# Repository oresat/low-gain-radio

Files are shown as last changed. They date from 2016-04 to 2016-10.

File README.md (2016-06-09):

# OreSat "Low Gain Radio" board

<p align="center">
  
</p>

## Overview

The Low Gain Radio module is part of the sputnik capstone project and is the communications pipeline for the CubeSat.  

OreSat to LGR block diagram  

The module is centered around a microcontroller with an integrated transceiver and RF front end. Commands will be sent and received through this module. In most cases the system controller will assist in executing those commands. Communication with the system controller is done via a UART connection between the two modules.

## Main Topics
[Parts Selection](https://github.com/oresat/low-gain-radio/blob/master/docs/Parts_Selection.md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)  
[Bill of Materials](https://github.com/oresat/low-gain-radio/blob/master/docs/low-gain-radio_BOM.xlsx)  
[Eagle Schematic](https://github.com/oresat/low-gain-radio/blob/master/eagle/low-gain-radio.sch)    
[Eagle Layout](https://github.com/oresat/low-gain-radio/blob/master/eagle/low-gain-radio.brd)    
[Test Plan](https://github.com/oresat/low-gain-radio/blob/master/docs/Test_Plan_Sputnik_Capstone.md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)    

## Contents

datasheets - datasheets for components used

docs - documentation

eagle - contains Schematic and PCB layout for the Low Gain Radio

tools - contains firmware and tools for compiling/debugging

## Project team

Industry Sponsor: Andrew Greenberg (adg@ece.pdx.edu)

Faculty Advisor: Dr. Christof Teuscher (teuscher@pdx.edu)

* Capstone Team
* 
    * Jake Heath (jakeheath@gmail.com)

    * Shan Quinney (quinney@pdx.edu) 

    * William Harrington (wrh2@pdx.edu)

    * Mike Mathis (mdmathis@gmail.com)

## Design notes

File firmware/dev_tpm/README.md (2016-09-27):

# dev_tpm

* This directory is for development of the tpm driver

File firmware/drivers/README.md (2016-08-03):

### Drivers for peripherals on microcontroller

* transceiver

* v1_2
	* V1_2 refers to the board revision. Specific configuration for this version of the board

* clocks

* led

* port

* uart

* spi

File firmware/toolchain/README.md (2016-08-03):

### Code Style

* see psas.astylerc

### Openocd configuration

#### Programmer

* In the olimex programmer cfg file for openocd you may need to change this line if you are using a different programmer

* select appropriate programmer by hand

* This one:
* source [find interface/ftdi/olimex-arm-usb-tiny-h.cfg]
* OR:
source [find interface/ftdi/olimex-arm-usb-ocd.cfg]

#### Configuration files

* olimex_swd_kinetis.cfg
* gdboocd_ocd.cmd

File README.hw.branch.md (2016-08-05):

## Branch for kw0x breakout board

### Branch rulez

#### Each version of hardware will have it's own branch

* Don't merge this branch into another hw branch 
* Don't merge this branch back into 'master'
* New hardware derived from this hardware should have it's own branch

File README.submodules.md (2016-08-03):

* Check the .gitmodules file for updates

* CMSIS from the ARM-software Github account
  * https://github.com/ARM-software/CMSIS.git

* common submodule commands
 * git submodule init
 * git submodule update

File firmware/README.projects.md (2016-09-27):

### Current project types for lgr 

* dev\_\*
 * Development code and experiments

* test
 * Accumulated tests that should execute before committing to main branch

* flight
 * This project is analogous to the 'release'. This is what is programmed to the flight board instance.

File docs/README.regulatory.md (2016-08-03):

# 70 cm Low Gain Radio Communications Transceiver

## Regulatory :us:

* **Frequency:** 436.5MHz  (70cm (420-450 MHz)) 
* **Power:** 1W
* **Band Plan** (Ref: http://www.arrl.org/band-plan)
    * 435.00-438.00	Satellite only (internationally)	

### Power Regulations

* There is a geographical power limitation on the 70cm band which does not apply at this frequency or output power.

   * Ref: FCC §97.313 Transmitter power standards. 

> (f) No station may transmit with a transmitter power exceeding 50 W PEP on the
>     UHF 70 cm band from an area specified in paragraph (a) of footnote US270 in
>     §2.106, unless expressly authorized by the FCC after mutual agreement, on a
>     case-by-case basis, between the District Director of the applicable field
>     facility and the military area frequency coordinator at the applicable military
>     base. An Earth station or telecommand station, however, may transmit on the
>     435-438 MHz segment with a maximum of 611 W effective radiated power (1 kW
>     equivalent isotropically radiated power) without the authorization otherwise
>     required. The transmitting antenna elevation angle between the lower half-power
>     (−3 dB relative to the peak or antenna bore sight) point and the horizon must
>     always be greater than 10°. 

### Auxiliary Station Operation

**NOTE** *This needs review*

* **Ref:**  http://www.arrl.org/auxiliary-station-faq

> What is an auxiliary station?- When an amateur station, such as a repeater, is
> remotely controlled over a radio link, there is another station involved--the
> station doing the controlling. This "control" station is, under the FCC rules,
> called an auxiliary station defined by the FCC as "An amateur station, other
> than a message forwarding system, that is transmitting comunications
> point-to-point within a system of cooperating amateur stations [97.3(a)(7)]."
> There are a few important rules that apply to auxiliary stations: 1) All
> amateurs, except Novices, may put auxiliary stations on the air [97.201(a)]. 2)
> An auxiliary station may transmit only on the 2 m and shorter wavelength bands,
> except the 144.0-144.5 MHz, 145.8-146.0 MHz, 219-220 MHz, 222.00-222.15 MHz,
> 431-433 MHz, and 435-438 MHz segments. 3) When there is interference, licensees
> are equally responsible for solving the interference, except where one station
> is coordinated and the other is not [97.201(c)]. Control links should be
> coordinated. 4) An auxiliary station may, under certain circumstances, be
> automatically controlled and may send one-way transmissions [97.201(d), (e)].

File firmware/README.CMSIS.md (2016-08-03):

### CMSIS
  * Submodule in lgr

#### Cortex Microcontroller Software Interface Standard

* http://www.arm.com/products/processors/cortex-m/cortex-microcontroller-software-interface-standard.php

#### lgr CMSIS usage

* Check included headers for CMSIS support. For example:
 * #include "core_cm0plus.h"
 * #include "cmsis_gcc.h"

```
	CMSIS
	├── ARM.CMSIS.pdsc
	├── CMSIS
	│   ├── CMSIS_END_USER_LICENCE_AGREEMENT.pdf
	│   ├── CMSIS_END_USER_LICENCE_AGREEMENT.rtf
	│   ├── DAP
	│   ├── Documentation
	│   ├── Driver
	│   ├── DSP_Lib
	│   ├── Include
	│   │   ├── arm_common_tables.h
	│   │   ├── arm_const_structs.h
	│   │   ├── arm_math.h
	│   │   ├── cmsis_armcc.h
	│   │   ├── cmsis_armcc_V6.h
	│   │   ├── cmsis_gcc.h
	│   │   ├── core_cm0.h
	│   │   ├── core_cm0plus.h
	│   │   ├── core_cm3.h
	│   │   ├── core_cm4.h
	│   │   ├── core_cm7.h
	│   │   ├── core_cmFunc.h
	│   │   ├── core_cmInstr.h
	│   │   ├── core_cmSimd.h
	│   │   ├── core_sc000.h
	│   │   └── core_sc300.h
	│   ├── index.html
	│   ├── Lib
	│   ├── Pack
	│   ├── RTOS
	│   ├── SVD
	│   └── Utilities
	├── Device
	│   ├── ARM
	│   ├── _Template_Flash
	│   └── _Template_Vendor
	└── README.md
```

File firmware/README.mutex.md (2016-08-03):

#### FYI: Atomic instructions

* http://infocenter.arm.com/help/index.jsp?topic=/com.arm.doc.dai0321a/BIHEJCHB.html
 * The Cortex-M0 and Cortex-M0+ processors do not have exclusive access instructions.

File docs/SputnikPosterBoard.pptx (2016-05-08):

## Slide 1

Sputnik: Command, Control and Communications Board for Cubesat

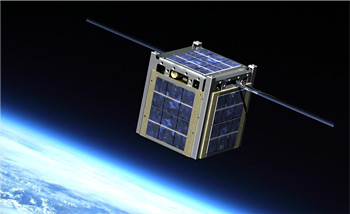
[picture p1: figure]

Description
The Portland State Aerospace Society (PSAS) needs a command, control, and communications system for their CubeSat project. The focus of this project will be rapidly prototyping this module. The code name for the module is Sputnik because of it's requirements to be a simple, reliable space system.
Sputnik will have the following responsibilities:
Long distance RF communications to and from a 400km Low Earth Orbit
Controlling and communicating with a payload that is housed within the CubeSat
On top of fulfilling these duties, it will need to be able to deal with a temperature range of -40C to 50C and radiation events that could cause components to latch up. It will have to have a way for dealing with these events such as rebooting the entire module and/or fault-tolerance.
Aspects of this project include
Building a C3 system from scratch to meet
The harsh environment of space
Compliance with governmental regulations
Programming the system to perform the aforementioned duties
Testing and verifying the device
Documentation
Adhering to the PSAS open-source standard

Concept
The Sputnik module is split up in two separate submodules: the radio transceiver module and control module. It is connected to two other important modules within the CubeSat: the payload module and power module.
At the heart of Sputnik is the Radio transceiver which contains the KW0x and a radio infrastructure. This is the communications pipeline. It is connected to the Control Module via UART.
The radio infrastructure in this submodule will consist of a bandpass filter, AC blocking network, aLow-Noise Amplifier, and a Power Amplifier. It will be expecting a 50ohm impedance for its load (the antenna) which is not within the scope of this project. It will need to be capable of producing 1 Watt of power for long distance communication.
The Payload is its own separate module that is not within the scope of this project. What it contains is undetermined but it can be assumed that it will consist of other electronic modules capable of UART communication.
The Control Module is composed entirely of rad-hard parts. It is the lifeline of Sputnik. It will be responsible for detecting the first sign of trouble and rebooting the module. It is also connected to the Power module via I2C and to the Payload via UART. Provisions will need to be made to ensure that the microcontroller is given a little bit of charge during a reboot cycle so that it can maintain control.
The entire architecture will have to run off of a single cell Li-Po battery pack that is connected to the Power module. The Power Management System will take input power from 6 photovoltaic cells. It will use this input power to charge the battery and power the module when possible. When there is no input power, the module will run off the battery.

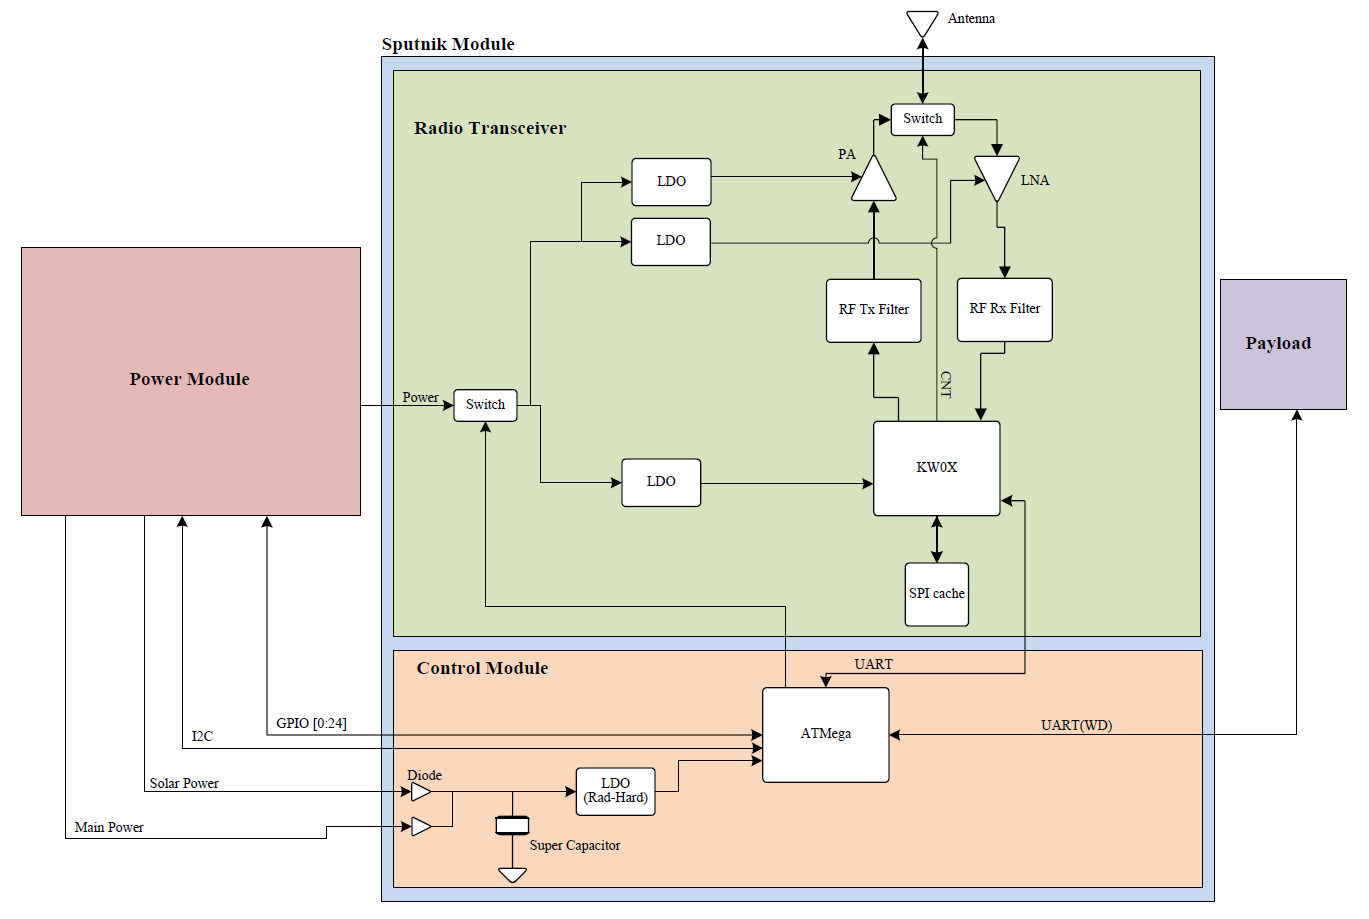
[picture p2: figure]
Phase 1 Low Level Diagram
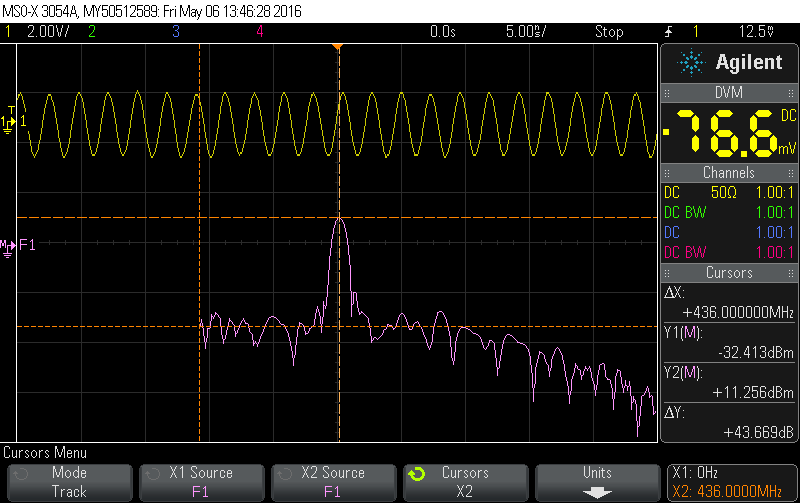
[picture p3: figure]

Department of Electrical and Computer Engineering

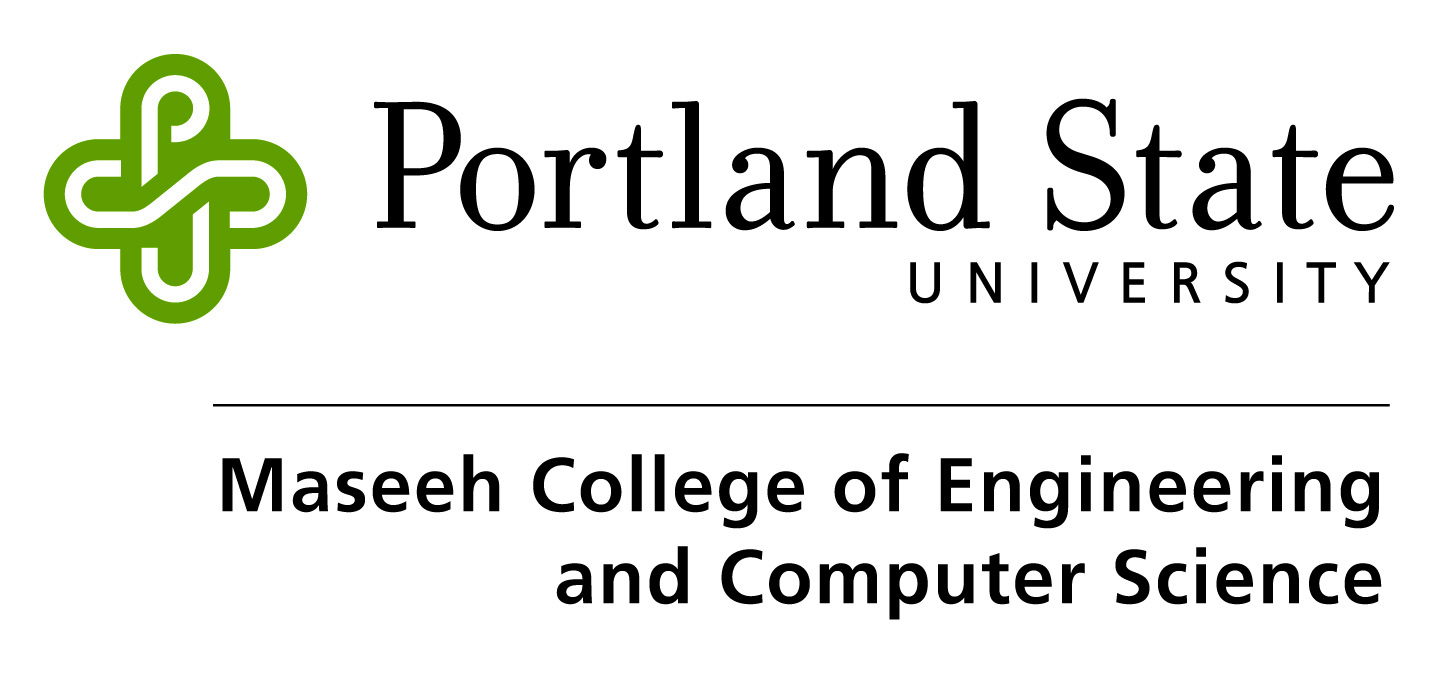
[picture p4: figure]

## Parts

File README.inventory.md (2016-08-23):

### Version 1.2 boards

* Three boards total from OSHPARK.

* DIO0 Modwire: DIO0 was incorrectly connected to RESET (RF) during design.
 * This prevents DIO0 from being used as a Packet Mode information pin.
 * Reference: Table 7-3 p.7-7 MKW01xxRM Reference Manual, Rev. 3, 04/2016

#### Board A

* DIO0 Modwire	PTE30 -> RESET (RF)    Wed 02 August 2016
* Location: Jake Heath

#### Board B

* DIO0 Modwire
* Fails to program flash. Thu 18 August 2016 13:12:48 (PDT)
* Location: K Wilson 

#### Board C

* DIO0 Modwire
* Program flash but fails at switch to PLL clock. Thu 18 August 2016 13:13:02 (PDT)
* Location: K Wilson

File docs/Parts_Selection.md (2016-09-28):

# Parts Selection for Low Gain Radio  
**Table of Contents**
 * [Microcontroller](https://github.com/oresat/low-gain-radio/blob/v1_2/docs/Parts_Selection.md#u1-nxp-mkw01z128)   
 * [PA](https://github.com/oresat/low-gain-radio/blob/v1_2/docs/Parts_Selection.md#u2-skyworks-sky65116)  
 * [LNA](https://github.com/oresat/low-gain-radio/blob/v1_2/docs/Parts_Selection.md#u8-maacom-maal-010704)  
 * [RF-Switch](https://github.com/oresat/low-gain-radio/blob/v1_2/docs/Parts_Selection.md#u9-rfmd-rf3025tr7)  
 * [MCU LDO](https://github.com/oresat/low-gain-radio/blob/v1_2/docs/Parts_Selection.md#u4-texas-instruments-lp5907mfx-33)  
 * [PA LDO](https://github.com/oresat/low-gain-radio/blob/v1_2/docs/Parts_Selection.md#u7-st-microelectronics-dm00102135)
 * [LNA LDO](https://github.com/oresat/low-gain-radio/blob/v1_2/docs/Parts_Selection.md#u6-texas-instruments-lp5907mfx-33)  
 * [SPI Cache](https://github.com/oresat/low-gain-radio/blob/v1_2/docs/Parts_Selection.md#u3-winbond-w25q80dvsnig-tr)  
 * [Crystal](https://github.com/oresat/low-gain-radio/blob/v1_2/docs/Parts_Selection.md#y1-epson-fa-20h)  
 * [JTAG Connector](https://github.com/oresat/low-gain-radio/blob/v1_2/docs/Parts_Selection.md#cm1-cnc-tech-3220-10-0100-00)
 * [40 Pin Header](https://github.com/oresat/low-gain-radio/blob/v1_2/docs/Parts_Selection.md#y1-harwin-inc-m50-3202045)
 * [MCX Connector](https://github.com/oresat/low-gain-radio/blob/v1_2/docs/Parts_Selection.md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) 
 * [Inverter](https://github.com/oresat/low-gain-radio/blob/v1_2/docs/Parts_Selection.md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)
 * [RF Shield (1)](https://github.com/oresat/low-gain-radio/blob/v1_2/docs/Parts_Selection.md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)
 * [RF Shield (2)](https://github.com/oresat/low-gain-radio/blob/v1_2/docs/Parts_Selection.md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)
 * [Electrolytic Capacitor](https://github.com/oresat/low-gain-radio/blob/v1_2/docs/Parts_Selection.md#c43-avx-tajc107k010rnj)
 * [LEDs](https://github.com/oresat/low-gain-radio/blob/v1_2/docs/Parts_Selection.md#leds)
 * [Capacitors](https://github.com/oresat/low-gain-radio/blob/v1_2/docs/Parts_Selection.md#capacitors)
 * [Inductors](https://github.com/oresat/low-gain-radio/blob/v1_2/docs/Parts_Selection.md#inductors)
 * [Resistors](https://github.com/oresat/low-gain-radio/blob/v1_2/docs/Parts_Selection.md#resistors)

#### Format note  
Eagle Referance, Manufacturer, Manufacturer's Part Number  
Vendor  
Vendor Part No  
Datasheet  
Reasons  
Rad-hard Analogue  

#### U1 NXP MKW01Z128:  
Part: Microcontroller  
Vendor: Digi-Key  
Vendor Part No.: MKW01Z128CHN-ND  
[Datasheet](http://cache.nxp.com/files/microcontrollers/doc/data_sheet/MKW01Z128.pdf)  
Reasons: Requirement for the project. Chosen since it has an integrated transceiver, needed peripherals and meets JDEC standards.     
Rad-Hard Analogue: N/A  
  
#### U2 SkyWorks SKY65116: 
Part: Power Amplifier  
Vendor: Mouser    
Vendor Part No.: 873-SKY65116-21  
[Datasheet](http://www.skyworksinc.com/uploads/documents/SKY65116_200510I.pdf)  
Reasons: Able to provide 1W power output. Also has low voltage rails, but asks for a higher current draw (~1-1.3A).  
Rad-Hard Analogue: N/A  
  
#### U8 MAACOM MAAL-010704:  
Part: Low Noise Amplifier  
Vendor: Digi-Key    
Vendor Part No.: 1465-1261-1-ND  
[Datasheet](http://cdn.macom.com/datasheets/MAAL-010704.pdf)  
Reasons: Provides >0.7dB Noise level at average space temperatures (~-40C) at 436.5MHz. At different temperatures, we see an increase of about .1~.2dBs at the same frequency, so it's not perfect though. 
Rad-Hard Analogue: N/A  
**_Alternatives_**     
Part No.: HMC616LP3    
Manufacturer: Hittite  
[Datasheet](http://www.radiant.su/other/hittite/pdf/hmc616lp3.pdf)  
Reasons: This part would be better than the one selected. Provides >0.6dB Noise at all temperatures and at most frequencies. At average space temperatures, around 0.3dB Noise level at 436.5MHz. However it is vaporware in the USA. It might be available from China, however shipping and part price is expensive/long.  
Part No.: SKY67110_396LF  
Manufacturer: SkyWorks  
[Datasheet](http://www.skyworksinc.com/uploads/documents/SKY67110_396LF_201792B.pdf)  
Reasons: Brand new part from Skyworks. Would work better than what we have. Has a gain of ~21dB at desired frequency and a noise figure of 0.65dB at 25C and around 0.5dB at 40C. Seems like a slightly more complicated setup however.   

#### U9 RFMD RF3025TR7:    
Part: RF Switch   
Vendor: Digi-Key  
Vendor Part No.: 689-1087-1-ND    
Part No.: RF3025TR7    
Manufacturer: RFMD  
[Datasheet](http://www.rfmd.com/store/downloads/dl/file/id/28477/rf3025_data_sheet.pdf)  
Reasons: Better footprint for the kw0x lines than the SkyWorks card. Allows for the high input power (~+32 dBm) with low insertion loss (0.45 dB). Also can be used for 50 ohm impedance matching.   
**_Alternatives_**  
Part No.: PE42723A-Z      
Manufacturer: Peregrine-Semiconductor    
[Datasheet](http://www.psemi.com/pdf/datasheets/pe42723ds.pdf)  
Reasons: Better footprint for the way the kw0x outputs Tx and Rx. This would get rid of the need for an inverter. Also has a better insertion loss and similar footprint. This switch was implemented in the stead of the SkyWorks one below. Matched impedance however was 75 Ohms, so not worth the hassle of reconfiguring a matching network.     
Part No.: SKY13405_490F      
Manufacturer: Skyworks  
[Datasheet](http://www.skyworksinc.com/uploads/documents/SKY13405_490LF_201609I.pdf)  
Reasons: Comes from SkyWorks which has been a reliable manufacturer for RF parts for this project (such as the PA). Small footprint, it has a low insertion loss and works within the desired frequency range. However, requires reverse topology in order to reduce power usage for the kw0x. Could be used with an inverter if real-estate or complexity is no issue.     
Rad-Hard Analogue: N/A  

#### U4 Texas Instruments LP5907MFX-3.3:  
Part: LNA LDO  
Vendor: Digi-Key    
Vendor Part No.: 296-38557-1-ND      
[Datasheet](http://www.ti.com/lit/ds/symlink/lp5907.pdf)  
Reasons: Same LDO as MCU so easy to access and cheaper to buy. Again, it also has low noise rejection. Also has internal pull-down resistors and the same footprint as the AAT3215 which is what we originally designed the board to use.    
Rad-Hard Analogue: N/A    
**_Alternatives_**    
Part No.: AAT3215    
Manufacturer: Skyworks    
[Datasheet](http://www.skyworksinc.com/uploads/documents/AAT3215_202408B.pdf)  
Reasons: This was the original choice, but manufacturing stopped during the design period, meaning we could only purchase parts by the 3,000 instead of 1 at a time.   
Part No.: TPS789xx      
Manufacturer: Texas Instruments  
[Datasheet](http://www.mouser.com/ds/2/405/tps789-558350.pdf)  
Reasons: Works, but went with the same LDO as the LNA for simplicity and cost effectiveness.  
 
#### U7 ST Microelectronics DM00102135:  
Part: PA LDO  
Vendor: Digi-Key  
Vendor Part No.: 497-15229-2-ND  
[Datasheet](http://www.mouser.com/ds/2/389/DM00102135-524580.pdf)  
Reasons:  The PA requires a high current draw, much larger than the LNA or MCU so it required its own LDO. This LDO allows for up to 2A output, which is about 500mA above what's required. Also looking for a low drop-out voltage which this has a fairly decent value at 250mV at max.  
Rad-Hard Analogue: N/A  

#### U6 Texas Instruments LP5907MFX-3.3:  
Part: LNA LDO  
Vendor: Digi-Key    
Vendor Part No.: 296-38557-1-ND      
[Datasheet](http://www.ti.com/lit/ds/symlink/lp5907.pdf)  
Reasons: Same LDO as MCU so easy to access and cheaper to buy. Again, it also has low noise rejection. Also has internal pull-down resistors and the same footprint as the AAT3215 which is what we originally designed the board to use.    
Rad-Hard Analogue: N/A    
**_Alternatives_**    
Part No.: AAT3215   
Manufacturer: Skyworks    
[Datasheet](http://www.skyworksinc.com/uploads/documents/AAT3215_202408B.pdf)  
Reasons: This was the original choice, but manufacturing stopped during the design period, meaning we could only purchase parts by the 3,000 instead of 1 at a time.  

#### U3 Winbond W25Q80DVSNIG TR:  
Part: SPI Cache  
Vendor: Digi-Key  
Vendor Part No.: W25Q80DVSNIG CT-ND    
[Datasheet](http://www.winbond.com/resource-files/w25q80dv_revf_02112015.pdf)  
Reasons: 8MB worth of storage for a boot loader. Easy hardware implementation.   
Rad-Hard Analogue: N/A  
**_Alternative_**       
Part No.: LE25FU406BMB     
Manufacturer: SANYO      
[Datasheet](http://media.digikey.com/pdf/Data%20Sheets/ON%20Semiconductor%20PDFs/LE25FU406B.pdf)  
Reasons: 4MB storage. Unfortunately it was vaporware at the time and has less storage.   

#### Y1 Epson FA-20H:  
Part: MCU Crystal  
Vendor: Digi-Key   
Vendor Part No.: SER4044CT-ND  
[Datasheet](https://support.epson.biz/td/api/doc_check.php?dl=brief_FA-20H_en.pdf)  
Reasons: Fits the frequency we wanted at 32MHz for bumping up the integrated transceiver to 48MHz. High bit rate operations for 600kbits on the KW0x needed a crystal of maximum +- 15ppm, which this is 10ppm. Also fits within the temperature range of -40C-85C.    
Rad-Hard Analogue: Swept quartz is likely required for space operation. From some searching there seem to be none that fit the footprint of normal devices.  

#### CM1 CNC Tech 3220-10-0100-00:  
Part: JTAG Connector    
Vendor: Digi-Key  
Vendor Part No.: 1175-1627-ND    
[Datasheet](http://cnctech.us/pdfs/3220-XX-0100-00.pdf)  
Reasons: Supports serial wire debug interface which is the only one supported by our MCU.

#### CF1 Harwin Inc. M50-3202045:     
Part: 40-Pinout Header     
Vendor: Digi-Key  
Vendor Part No.: 952-1381-5-ND  	  
[Datasheet](https://cdn.harwin.com/pdfs/60page104.pdf)  
Reasons: Design requirement for communication from the Cubesat and allows for communication between the LGR and the System Controller.  

#### CF2 Linx Technologies Inc. CONMCX003.062:       
Part: MCX Connector   
Vendor: Digi-Key  
Vendor Part No.: CONMCX003.062-ND  	  
[Datasheet](http://www.linxtechnologies.com/resources/documents/mcx_rp-mcx_specs.pdf)  
Reasons: Connector for RF signal to the antenna on the back panel. Set at the back of the board next to the 40-Pinout so it can hook-up easily to the back panel of the Cubesat.  

#### U5A Fairchild Semiconductor NC7SZ05P5X:    
Part: Inverter       
Vendor: Digi-Key  
Vendor Part No.: NC7SZ05P5XTR-ND  	  
[Datasheet](https://www.fairchildsemi.com/datasheets/NC/NC7SZ05.pdf)  
Reasons: Inverter was needed since the PA and LNA outputs from the KW0x is reverse that of the RF Switch. In order to not have the lines cross, the inverter was used to invert the switch so that there wouldn't be a constant high voltage to the switch when receiving.  

#### SH1 Laird Technologies BMI-S-202-C BMI-S-202-F:     
Part: RF Shield 1    
Vendor: Digi-Key  
Vendor Part No. Shield: 903-1014-ND
Vendor Part No. Mount: 903-1051-1-ND  
[Datasheet Shield](http://cdn.lairdtech.com/home/brandworld/files/Board%20Level%20Shields%20Catalog%20Download.pdf)  
[Datasheet Mount](http://media.digikey.com/pdf/Data%20Sheets/Laird%20Technologies/BMI-S-202.pdf)  
Reasons: RF shielding for the PA portion of the RF part of the board to prevent interference from other signals.

#### SH2 Laird Technologies BMI-S-202-C BMI-S-202-F:     
Part: RF Shield 2   
Vendor: Digi-Key  
Vendor Part No.: 903-1014-ND  	 
Vendor Part No. Mount: 903-1051-1-ND   
[Datasheet Shield](http://cdn.lairdtech.com/home/brandworld/files/Board%20Level%20Shields%20Catalog%20Download.pdf)  
[Datasheet Mount](http://media.digikey.com/pdf/Data%20Sheets/Laird%20Technologies/BMI-S-202.pdf)  
Reasons: RF shielding for the LNA portion of the RF part of the board to prevent interference from other signals.

#### C43 AVX TAJC107K010RNJ:    
Part: Tantalum Capacitors - Solid SMD 10volts 100uF 10%  
Vendor: Digi-Key  
Vendor Part No.: 478-1704-1-ND  	  
[Datasheet](http://datasheets.avx.com/TAJ.pdf)  
Reasons: 100 uF Electrolytic capacitor is used in the LNA schematic setup in accordance to the recommended circuit from the datasheet for a <0.7dB noise figure.

### LEDs
**LED1, LED2, LED3, LED4, Lite-On Inc. LTST-C191KGKT**:      
Part: Green LEDs    
Vendor: Digi-Key  
Vendor Part No.: 160-1446-1-ND  
[Datasheet](http://optoelectronics.liteon.com/upload/download/DS22-2000-228/S_110_LTST-C191KGKT.pdf)  
Reasons: Green LEDs are used for debugging power. The green LEDs are placed at the front of the board for easy viewing and when on represent that the power line of interest is working. There are LEDs for the 3.3V power supply from the LNA and MCU LDOs, V+ from the photovoltaic bus and for the LDO on the PA. These will be removed before the actual launch and are only used for debugging purposes.    

**LED5, LED6, LED7, LED8, Broadcom Limited HSMA-C120**:      
Part: Amber LEDs    
Vendor: Digi-Key  
Vendor Part No.: 516-2486-1-ND    
[Datasheet](http://www.avagotech.com/docs/AV02-0975EN)  
Reasons: Amber LEDs are used for error checks during debugging and are placed on the debugging lines for PTC1-4. They will also be removed before actual launch.

### Capacitors

**C1, C3, C16, C18, C20, C21, C37, C40 Murata GRM188R71H103KA01D**:       
Part: Multilayer Ceramic Capacitors MLCC - SMD/SMT 0603 0.01uF 50volts X7R 10%  
Vendor: Digi-Key  
Vendor Part No.: 490-1512-2-ND  
[Datasheet](http://www.murata.com/~/media/webrenewal/support/library/catalog/products/capacitor/mlcc/c02e.ashx)  
Reasons: C1 and C3 are used for the feed network filter to prevent RF feedback into the MCUs VR_PA pins. They are designated by the kw0x datasheet. C16, C18, C20, and C21 are bypass capacitors on the PA as designated by the PA datasheet. Both C37 and C40 are used for the bypass line on the AAT3215 LDOs for both the MCU and LNA and are also dictated by their datasheet.   

**C2, C4 Murata GRM1885C1H120JA01D**:        
Part: Multilayer Ceramic Capacitors MLCC - SMD/SMT 0603 12pF 50volts C0G 5%  
Vendor: Digi-Key  
Vendor Part No.: 490-1405-2-ND  
[Datasheet](http://www.murata.com/~/media/webrenewal/support/library/catalog/products/capacitor/mlcc/c02e.ashx)  
Reasons: Used in part of the filter for both the Tx and Rx lines in effort to filter the signal to 436.5 MHz.    

**C5, C6, C9, C10 Murata GRM1885C1H150JA01D**:       
Part: Multilayer Ceramic Capacitors MLCC - SMD/SMT 0603 15pF 50volts C0G 5%  
Vendor: Digi-Key  
Vendor Part No.: 490-1407-2-ND  
[Datasheet](http://www.murata.com/~/media/webrenewal/support/library/catalog/products/capacitor/mlcc/c02e.ashx)  
Reasons: Used in part of the filter for both the Tx and Rx lines in effort to filter the signal to 436.5 MHz.   

**C7, C8 Murata GRM1885C1H2R2CA01D**:       
Part: Multilayer Ceramic Capacitors MLCC - SMD/SMT 0603 2.2pF 50volts C0G +/-0.25pF  
Vendor: Digi-Key  
Vendor Part No.: 490-9668-2-ND  
[Datasheet](http://www.murata.com/~/media/webrenewal/support/library/catalog/products/capacitor/mlcc/c02e.ashx)  
Reasons: Used in part of the filter for both the Tx and Rx lines in effort to filter the signal to 436.5 MHz.      

**C11, C12 Murata GQM1885C1H8R2CB01D**:       
Part: Multilayer Ceramic Capacitors MLCC - SMD/SMT 25 volts 8.2pF ULTRA LOW ESR  
Vendor: Mouser  
Vendor Part No.: 81-GQM1885C1H8R2CB01    
[Datasheet](http://datasheets.avx.com/AutoU_Series.pdf)  
Reasons: Used in part of the filter for both the Tx and Rx lines in effort to filter the signal to 436.5 MHz.  

**C13, C15, C17, C19, C22, C38, C41, C52, C53 Murata GRM188R60J106ME47J**:       
Part: Multilayer Ceramic Capacitors MLCC - SMD/SMT 10uF 6.3Volts 20%  
Vendor: Digi-Key  
Vendor Part No.: 490-6405-2-ND  
[Datasheet](http://search.murata.co.jp/Ceramy/image/img/A01X/G101/ENG/GRM188R60J106ME47-01.pdf)  
Reasons: C13 is a bypass capacitor on the PA LDO in accordance to the datasheet. C15, C17, C19, and C22 are bypass capacitors on the PA voltage lines also in accordance to the datasheet. Used as bypass caps on the LDO's vbias lines for the kw0x and LNA in accordance to the datasheet. C53 is something Andrew did.      

**C14, C26, C27, C28, C30, C31, C32, C33, C42, C45, C47, C48, C49 AVX 06035C104JAT2A**:       
Part: Multilayer Ceramic Capacitors MLCC - SMD/SMT 50volts 0.1uF 5% X7R  
Vendor: Digi-Key  
Vendor Part No.: 478-5778-1-ND  
[Datasheet](http://datasheets.avx.com/X7RDielectric.pdf)  
Reasons: C14 is a coupling capacitor between the PA and the 436.5 MHz filter. All the other 100nF capacitors are used as bypass capacitors valued in accordance to the datasheets.    

**C23, C24, C25 Murata GRM155R71H102KA01D**:       
Part: Multilayer Ceramic Capacitors MLCC - SMD/SMT 0402 1000pF 50volts X7R 10%  
Vendor: Digi-Key  
Vendor Part No.: 490-1303-1-ND  
[Datasheet](http://search.murata.co.jp/Ceramy/image/img/A01X/G101/ENG/GRM155R71H102KA01-01.pdf)  
Reasons: The capacitors on the LNA are used in accordance to the datasheet. MACOM requested 0402s for these parts due to the LNAs possible sensitivity.    

**C34, C35 Murata GQM1885C2A6R0CB01D**:       
Part: Multilayer Ceramic Capacitors MLCC - SMD/SMT 0603 6.0pF 100volts C0G +/-0.25pF  
Vendor: Digi-Key  
Vendor Part No.: 490-3561-1-ND    
[Datasheet](http://search.murata.co.jp/Ceramy/image/img/A01X/G101/ENG/GQM1875C2E6R0BB12-01.pdf)  
Reasons: Bypass capacitors on the Epson crystal for the MCU.    

**C36, C39 Murata GRM188R61A105KA61D**:       
Part: Multilayer Ceramic Capacitors MLCC - SMD/SMT 0603 1uF 10volts X5R 10%  
Vendor: Digi-Key  
Vendor Part No.: 490-1543-2-ND  
[Datasheet](http://search.murata.co.jp/Ceramy/image/img/A01X/G101/ENG/GRM188R61A105KA61-01.pdf)  
Reasons: Bypass capacitors on the AAT3215 LDOs in accordance to their datasheet.    

**C44 Murata GRM155R71H103KA88D**:       
Part: Multilayer Ceramic Capacitors MLCC - SMD/SMT 0402 0.01uF 50volts X7R 10%  
Vendor: Digi-Key  
Vendor Part No.: 490-4516-1-ND  
[Datasheet](http://search.murata.co.jp/Ceramy/image/img/A01X/G101/ENG/GRM155R71H103KA88-01.pdf)  
Reasons: Bypass capacitor for the LNA Vbias line. The values used here were suggested directly from the manufacturer allow for the proper noise factor at 436.5 MHz.    

**C46 Murata GRM188R60J106ME47J**:       
Part: Multilayer Ceramic Capacitors MLCC - SMD/SMT 10uF 6.3Volts 20%  
Vendor: Digi-Key  
Vendor Part No.: 490-6405-2-ND  
[Datasheet](http://search.murata.co.jp/Ceramy/image/img/A01X/G101/ENG/GRM188R60J106ME47-01.pdf)  
Reasons: Output bypass capacitor on the PA LDO in accordance to the recommended circuit from the datasheet.  

**C50, C51, C54 Murata GRM155R71H102KA01D**:       
Part: Multilayer Ceramic Capacitors MLCC - SMD/SMT 0402 1000pF 50volts X7R 10%  
Vendor: Digi-Key  
Vendor Part No.: 490-1303-1-ND  
[Datasheet](http://search.murata.co.jp/Ceramy/image/img/A01X/G101/ENG/GRM155R71H102KA01-01.pdf)  
Reasons: C50 and C51 are filters for the debugging LEDs. C54 isa filter between V+ and the RF_GND.   

#### Inductors

**L1, L2 Murata LQW18AN22NG00D**:  
Part: Fixed Inductors 0603 22nH 2% 500mA  
Vendor: Digi-Key  
Vendor Part No.: 490-6874-1-ND  
[Datasheet](http://search.murata.co.jp/Ceramy/image/img/PDF/ENG/L0075S0080LQW18A_00.pdf)  
Reasons: L1 and L2 are used for the feed network filter to prevent RF feedback into the MCUs VR_PA pins. They are designated by the kw0x datasheet.    

**L3, L4, L5, L6 Murata LQW18AN15NG00D**:  
Part: Fixed Inductors 0603 15nH  
Vendor: Digi-Key  
Vendor Part No.: 490-6866-1-ND  
[Datasheet](http://search.murata.co.jp/Ceramy/image/img/PDF/ENG/L0075S0080LQW18A_00.pdf)  
Reasons: Used in part of the filter for both the Tx and Rx lines in effort to filter the signal to 436.5 MHz.  

**L8 Murata LQW18AN82NG00D**:  
Part: Fixed Inductors 0603 82nH  
Vendor: Digi-Key  
Vendor Part No.: 490-6912-2-ND  
[Datasheet](http://search.murata.co.jp/Ceramy/image/img/PDF/ENG/L0075S0080LQW18A_00.pdf)  
Reasons: Used in the LNA Vbias to the output. Value was suggested by manufacturer for optimum Noise Factor (<0.7dB) at desired frequency of 436.5 MHz.  

#### Resistors

**R1	Samsung	RC1608F2490CS**:      
Part: RES SMD 249 OHM 1% 1/10W 0603  
Vendor: Digi-Key  
Vendor Part No.: 1276-4592-2-ND  
[Datasheet](http://media.digikey.com/pdf/Data%20Sheets/Samsung%20PDFs/RC_Series_ds.pdf)  
Reasons: Used in the LNA Vbias to the output. Value was suggested by manufacturer for optimum Noise Factor (<0.7dB) at desired frequency of 436.5 MHz.    

**R2, R3, R5	Yageo RC0603FR-0710KL**:      
Part: Thick Film Resistors - SMD 10K OHM 1%  
Vendor: Digi-Key  
Vendor Part No.: 311-10.0KHRCT-ND  
[Datasheet](http://www.yageo.com/documents/recent/PYu-RC_Group_51_RoHS_L_04.pdf)  
Reasons: Pull-up resistors on the power lines for the LDO and the SPI Cache's !HOLD and !WP.

**R4, R8, R9, R10, R11, R12 Yageo RC0603FR-071KL**:      
Part: Thick Film Resistors - SMD 1K OHM 1%  
Vendor: Digi-Key  
Vendor Part No.: 311-1.00KHRCT-ND  
[Datasheet](http://www.yageo.com/documents/recent/PYu-RC_Group_51_RoHS_L_04.pdf)  
Reasons: LED current limiting resistors. DNPs for launch.

**R6, R7 Yageo RC0603FR-071KL**:      
Part: Thick Film Resistors - SMD 1K OHM 1%    
Vendor: Digi-Key  
Vendor Part No.: 311-1.00KHRCT-ND  
[Datasheet](http://www.yageo.com/documents/recent/PYu-RC_Group_51_RoHS_L_04.pdf)  
Reasons: Current limiting resistor for PA and LNA LDO LEDs. DNPs for launch.

**R13, R14 Yageo RC0603JR-070RL**:      
Part: Thick Film Resistors - SMD ZERO OHM JUMPER  
Vendor: Digi-Key  
Vendor Part No.: 311-0.0GRTR-ND  
[Datasheet](http://www.yageo.com/documents/recent/PYu-RC_Group_51_RoHS_L_04.pdf)  
Reasons: Used for the separate ground between the signal and the LEDs for debugging. DNPs for launch.

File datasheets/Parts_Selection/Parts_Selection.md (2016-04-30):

### Parts Selection

##### Radio MCU:
[Datasheet](http://cache.nxp.com/files/microcontrollers/doc/data_sheet/MKW01Z128.pdf)
Reasons: Requirement for the project
Rad-Hard Analog: N/A

##### KW0x LDO:
<http://www.mouser.com/ds/2/405/tps789-558350.pdf>
-Works, but went with the same LDO as the LNA for simplicity and cost effectiveness.
AAT3215 <http://www.skyworksinc.com/uploads/documents/AAT3215_202408B.pdf>
-Low Noise Rejection

##### System Controller MCU:
Rad-hard: <http://aerosupport.atmel.com/Atmel/doc41036S.pdf>
non-hardened: <http://www.atmel.com/images/doc2467.pdf>
-RadHard MCU that is easily programmable

##### SPI Cache:
LE25FU406BMB <http://media.digikey.com/pdf/Data%20Sheets/ON%20Semiconductor%20PDFs/LE25FU406B.pdf>
-4MB storage
-Vapor Ware so no go.
<http://www.winbond-usa.com/resource-files/w25q80dv_revf_02112015.pdf>
-8MB!

##### LNA LDO:
AAT3215 <http://www.skyworksinc.com/uploads/documents/AAT3215_202408B.pdf>
-Low Noise Rejection

##### PA LDO:
<http://www.st.com/web/en/resource/technical/document/datasheet/DM00102135.pdf>

##### LNA:
<http://cdn.macom.com/datasheets/MAAL-010704.pdf> or optimally <http://www.radiant.su/other/hittite/pdf/hmc616lp3.pdf>

##### MAACOM
-Provides >0.7dB Noise level at space temperatures at 436.5MHz
Hittite
-Provides >0.6dB Noise at all temperatures and at most frequencies.
-At space temperatures, around 0.3dB Noise level at 436.5MHz
-Bad thing: Vaporware in the USA. Looks like it has to be ordered from China

##### PA:
<http://www.skyworksinc.com/uploads/documents/SKY65116_200510I.pdf>
-Can provide 1W power output
-Low voltage rails, but this requires high current

##### RF Switch:
<http://www.skyworksinc.com/uploads/documents/SKY13405_490LF_201609I.pdf>

##### Possible radhard MOSFET:
<http://www.st.com/st-web-ui/static/active/en/resource/technical/document/datasheet/CD00295117.pdf>

##### Radhard LDO:
<http://www.intersil.com/content/dam/Intersil/documents/isl7/isl75052seh.pdf>
non-hardened part? <http://www.ti.com/lit/ds/symlink/tps7h1201-ht.pdf>
-same footprint, but inputs are different so not worth the trouble
Using the LNA LDO for the SysCon.

##### Radhard Diode:
Single:http://www.st.com/st-web-ui/static/active/en/resource/technical/document/datasheet/CD00241480.pdf
non-hardened part: http://www.digikey.com/product-detail/en/microsemi-hi-rel-mil/JANTXV1N5806US/1086-2843-MIL/4349180

Dual:http://www.st.com/st-web-ui/static/active/en/resource/technical/document/datasheet/CD00277085.pdf

##### Optoisolator:
<http://www.digikey.com/product-detail/en/toshiba-semiconductor-and-storage/TLP2160(TP,F)/TLP2160(TPF)CT-ND/5189796>
-Too complex
<http://www.avagotech.com/docs/AV02-2150EN>
-Much less complex, has both a dual and single option

##### Super Cap:
<http://www.elna.co.jp/en/capacitor/double_layer/catalog/pdf/ds_e.pdf>
-Already have footprint & symbol in Eagle.
-Known reliability on the GPS board
-Should provide about 50~60secs supply in the case of complete power down

##### Inverter:
<https://www.fairchildsemi.com/datasheets/NC/NC7SZ05.pdf>
-Meets Vcc range
-simple design
-small package

##### Efuse/Switch:
<http://www.ti.com/lit/ds/slvsce9/slvsce9.pdf.pdf>
-eFuse switch used for undervoltage protection, and current limit protection
-Can be used to monitor current draw and fault
-looked at other possibilities but this one gave us all the features we need without extra external circuitry

##### N-channel MOSFET:
<http://www.irf.com/product-info/datasheets/data/irlml6344pbf.pdf>
-Simple MOSFET as enable switch for the eFuse
-Small footprint (SOT-23) 
-Cheap

##### 16:1 Multiplexer
<http://cache.nxp.com/documents/data_sheet/74HC_HCT4067.pdf?pspll=1>
-Small footprint - VQFN-24 (3.5 mm x 5.50 mm)
-Supply voltage range: 2 - 10 V

##### 8:1 Multiplexer
<http://www.silabs.com/Support%20Documents/TechnicalDocs/TS410x.pdf>
- Small footprint - TQFN-16 (3.00 mm x 3.00 mm)
-Supply voltage range: 0.8 - 5.25 V
-Supply current of 675nA

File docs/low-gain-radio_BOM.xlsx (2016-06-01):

Bill Of Materials for PSAS Low Gain Radio (LGR)
source file: low-gain-radio.sch
Variant: NA
PCB version 1.0
BOM revision 0 |  | P/DNP = | Place/Do Not Place (DNP is for final production boards)
Last Modified: 2016.04.27 |  | Generic = | Any generic part with the same characteristics are OK (e.g., bypass cap)
Cnt | Part References | MFG | PN | P/DNP | Description | Vendor | Vendor-PN | Generic | Price/prt | Part Amounts | Total Price
7 | C1, C3, C16, C18, C20, C21, C37, C40 | Murata | GRM188R71H103KA01D |  | Multilayer Ceramic Capacitors MLCC - SMD/SMT 0603 0.01uF 50volts X7R 10% | Digi-Key | 490-1512-1-ND | Y | $0.01 | 50 | $0.50
2 | C2, C4 | Murata | GRM1885C1H120JA01D |  | Multilayer Ceramic Capacitors MLCC - SMD/SMT 0603 12pF 50volts C0G 5% | Digi-Key | 490-1405-1-ND | Y | $0.04 | 10 | $0.41
4 | C5, C6, C9, C10 | Murata | GRM1885C1H150JA01D |  | Multilayer Ceramic Capacitors MLCC - SMD/SMT 0603 15pF 50volts C0G 5% | Digi-Key | 490-1407-1-ND | Y | $0.02 | 50 | $1.11
4 | C7, C8, C38, C41 | Murata | GRM1885C1H2R2CA01D |  | Multilayer Ceramic Capacitors MLCC - SMD/SMT 0603 2.2pF 50volts C0G +/-0.25pF | Digi-Key | 490-9668-1-ND | Y | $0.05 | 10 | $0.53
2 | C11, C12 | AVX | 06031U8R2BAT2A |  | Multilayer Ceramic Capacitors MLCC - SMD/SMT 100volts 8.2pF ULTRA LOW ESR | Mouser | 581-06031U8R2BAT2A | Y | $0.34 | 50 | $17.10
8 | C13, C15, C17, C19, C22, C46, C52, C53 | Murata | GRM188R60J106ME47J |  | Multilayer Ceramic Capacitors MLCC - SMD/SMT 10uF 6.3Volts 20% | Digi-Key | 490-6405-1-ND | Y | $0.06 | 50 | $3.02
14 | C14, C26-C33, C42, C45, C47-C49 | AVX | 06035C104JAT2A |  | Multilayer Ceramic Capacitors MLCC - SMD/SMT 50volts 0.1uF 5% X7R | Digi-Key | 478-5778-1-ND | Y | $0.02 | 100 | $2.20
3 | C23-C25 | Murata | GRM155R71H102KA01D |  | Multilayer Ceramic Capacitors MLCC - SMD/SMT 0402 1000pF 50volts X7R 10% | Digi-key | 490-1303-1-ND | Y | $0.01 | 50 | $0.28
2 | C34, C35 | Murata | GQM1885C2A6R0CB01D |  | Multilayer Ceramic Capacitors MLCC - SMD/SMT 0603 6.0pF 100volts C0G +/-0.25pF | Digi-Key | 490-3561-1-ND | Y | $0.52 | 10 | $5.23
2 | C36, C39 | Murata | GRM188R61A105KA61D |  | Multilayer Ceramic Capacitors MLCC - SMD/SMT 0603 1uF 10volts X5R 10% | Digi-Key | 490-1543-1-ND | Y | $0.04 | 10 | $0.36
 | C43 | AVX | TAJC107K010RNJ |  | Tantalum Capacitors - Solid SMD 10volts 100uF 10% | Digi-Key | 478-1704-1-ND | Y | $1.25 | 5 | $6.25
 | C44 | Murata | GRM155R71H103KA88D |  | Multilayer Ceramic Capacitors MLCC - SMD/SMT 0402 0.01uF 50volts X7R 10% | Digi-key | 490-4516-1-ND | Y | $0.01 | 50 | $0.26
3 | C50, C51, C54 | Murata | GRM155R71H102KA01D |  | Multilayer Ceramic Capacitors MLCC - SMD/SMT 0402 1000pF 50volts X7R 10% | Digi-key | 490-1303-1-ND | Y | $0.01 | 10 | $0.10
 | CF1 | Harwin Inc. | M50-3202045 |  | CONN RCPT 1.27MM T/H R/A 40POS | Digi-key | 952-1381-5-ND | N | $5.73 | 4 | $22.92
 | CF2 | Linx Technologies Inc. | CONMCX003.062 |  | CONN MCX JACK 50 OHM EDGE MNT | Digi-key | CONMCX003.062 | N | $3.55 | 4 | $14.20
 | CM1 | CNC Tech | 3220-10-0100-00 |  | 10 Positions Header, Shrouded Connector 0.050" (1.27mm) Through Hole Gold | Digi-key | 1175-1627-ND | Y | $0.45 | 10 | $4.50
 | CM2/DNP |  |  | DNP | Debug PIN HEADER |  |  | Y | $0.45 | 5 | $2.25
2 | L1, L2 | Murata | LQW18AN22NG00D |  | Fixed Inductors 0603 22nH 2% 500mA | Digi-Key | 490-6874-1-ND | Y | $0.17 | 10 | $1.65
4 | L3-L6 | Murata | LQW18AN15NG00D |  | Fixed Inductors 0603 15nH | Digi-Key | 490-6866-1-ND | Y | $0.17 | 10 | $1.65
 | L8 | Murata | LQW18AN82NG00D |  | Fixed Inductors 0603 82nH | Digi-Key | 490-6912-1-ND | Y | $0.17 | 10 | $1.65
4 | LED1-LED4 | Lite-On Inc. | LTST-C191KGKT | DNP | LED GREEN CLEAR 0603 SMD | Digi-Key | 160-1446-1-ND | Y | $0.22 | 10 | $2.22
4 | LED5-LED8 | Broadcom Limited | HSMA-C120 | DNP | LED AMBER CLEAR 0603 SMD | Digi-Key | 516-2486-1-ND | Y | $0.49 | 10 | $4.86
 | R1 | Samsung | RC1608F2490CS |  | RES SMD 249 OHM 1% 1/10W 0603 | Digi-Key | 1276-4592-1-ND | Y | $0.01 | 10 | $0.14
3 | R2, R3, R5 | Yageo | RC0603FR-0710KL |  | Thick Film Resistors - SMD 10K OHM 1% | Digi-Key | 311-10.0KHRCT-ND | Y | $0.01 | 25 | $0.25
6 | R4, R8-R12 | Yageo | RC0603FR-071KL |  | Thick Film Resistors - SMD 1K OHM 1% | Digi-Key | 311-1.00KHRCT-ND | Y | $0.01 | 50 | $0.29
2 | R6, R7 | Yageo | RC0603FR-071KL | DNP | Thick Film Resistors - SMD 1K OHM 1%, DNP | Digi-Key | 311-1.00KHRCT-ND | Y | $0.01 | 100 | $1.40
2 | R13, R14 | Yageo | RC0603JR-070RL | DNP | Thick Film Resistors - SMD ZERO OHM JUMPER | Digi-Key | 311-0.0GRCT-ND | Y | $0.01 | 10 | $0.11
 | U1 | NXP | MKW01Z128CHN |  | RF Microcontrollers - MCU Kinetis W 32-bit MCU, ARM Cortex-M0+ core, 128KB Flash, 48 MHz, Sub-1GHz Radio, MAPBGA 60 | Digi-Key | MKW01Z128CHN-ND | N | $4.34 | 4 | $17.36
 | U2 | Skyworks | SKY65116 |  | RF Amplifier 390-500MHz Gain 35dB 3.6Volt -40C+85C | Mouser | 873-SKY65116-21 | N | $5.99 | 4 | $23.96
 | U3 | Winbond Electronics | W25Q80DVSSIG |  | IC FLASH 8MBIT 104MHZ 8SOIC | Digi-Key | W25Q80DVSNIG-ND | Y | $0.36 | 4 | $1.44
 | U4 | Texas Instruments | LP5907MFX-3.3 |  | IC REG LDO 3.3V 0.25A SOT23-5 | Digi-Key | 296-38557-1-ND | Y | $0.57 | 5 | $2.85
 | U5 | Fairchild Semiconductor | NC7SZ05P5X |  | IC INVERTER UHS OPEN DRN SC70-5 | Digi-Key | NC7SZ05P5XCT-ND | Y | $0.29 | 10 | $2.86
 | U6 | Texas Instruments | LP5907MFX-3.3 |  | IC REG LDO 3.3V 0.25A SOT23-5 | Digi-Key | 296-38557-1-ND | Y | $0.57 | 5 | $2.85
 | U7 | STMicroelectro | LD39200PU33R |  | LDO Voltage Regulators Linear Voltage Regulators & Vref | Digi-Key | 497-15229-1-ND | Y | $1.52 | 4 | $6.08
 | U8 | MACOM | MAAL-010704 |  | RF Amplifier 100-3500MHz 5.5Volt -40C +85C | Digi-Key | 1465-1261-1-ND | N | $3.00 | 4 | $12.00
 | U9 | Skyworks | SKY13405-490LF |  | RF Switch ICs .01-3GHz SP2T UHL Switch | Digi-Key | 863-1649-1-ND | N | $0.83 | 4 | $3.32
 | Y1 | EPSON | FA-20H 32.0000MF12Y-W3 |  | Crystals 32MHz 10ppm 12pF -30C +85C | Digi-Key | SER4044CT-ND | Y | $0.82 | 4 | $3.28
 | SH1 | Laird Technologies | BMI-S-202-C |  | BOARD SHIELD .65X.65" COVER | Digi-Key | 903-1014-ND | N | $1.29 | 5 | $6.43
 | SH1 | Laird Technologies | BMI-S-202-F |  | BOARD SHIELD .65X.65" FRAME | Digi-Key | 903-1051-1-ND | N | $1.66 | 5 | $8.29
 | SH2 | Laird Technologies | BMI-S-202-C |  | BOARD SHIELD .65X.65" COVER | Digi-Key | 903-1014-ND | N | $1.29 | 5 | $6.43
 | SH2 | Laird Technologies | BMI-S-202-F |  | BOARD SHIELD .65X.65" FRAME | Digi-Key | 903-1051-1-ND | N | $1.66 | 5 | $8.29
 |  |  |  |  |  |  |  |  |  |  | $200.89

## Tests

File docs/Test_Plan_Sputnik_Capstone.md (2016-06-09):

# Sputnik Capstone Test Plan

written by Shan Quinney, William Harrington, and James Heath

**Table of Contents**
* [Revision History](https://github.com/oresat/low-gain-radio/blob/master/docs/Test_Plan_Sputnik_Capstone.md#revision-history)
    * [Introduction](https://github.com/oresat/low-gain-radio/blob/master/docs/Test_Plan_Sputnik_Capstone.md#introduction)
    * [Purpose](https://github.com/oresat/low-gain-radio/blob/master/docs/Test_Plan_Sputnik_Capstone.md#purpose)
    * [Testing Procedure](https://github.com/oresat/low-gain-radio/blob/master/docs/Test_Plan_Sputnik_Capstone.md#testing-procedure)
    * [Recording of Results, witnessing, and authorities](https://github.com/oresat/low-gain-radio/blob/master/docs/Test_Plan_Sputnik_Capstone.md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)
* [Reference Documents](https://github.com/oresat/low-gain-radio/blob/master/docs/Test_Plan_Sputnik_Capstone.md#reference-documents)
    * [Design Documentation](https://github.com/oresat/low-gain-radio/blob/master/docs/Test_Plan_Sputnik_Capstone.md#design-documentation)
* [Overview](https://github.com/oresat/low-gain-radio/blob/master/docs/Test_Plan_Sputnik_Capstone.md#overview)
    * [Operational Description](https://github.com/oresat/low-gain-radio/blob/master/docs/Test_Plan_Sputnik_Capstone.md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)
* [Preparation](https://github.com/oresat/low-gain-radio/blob/master/docs/Test_Plan_Sputnik_Capstone.md#pre-test-preparation)
    * [Test Equipment](https://github.com/oresat/low-gain-radio/blob/master/docs/Test_Plan_Sputnik_Capstone.md#test-equipment)
    * [Test setup and calibration](https://github.com/oresat/low-gain-radio/blob/master/docs/Test_Plan_Sputnik_Capstone.md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)
* [Component Tests](https://github.com/oresat/low-gain-radio/blob/master/docs/Test_Plan_Sputnik_Capstone.md#component-tests)
     * [Supply Range Test](https://github.com/oresat/low-gain-radio/blob/master/docs/Test_Plan_Sputnik_Capstone.md#supply-range-test)
     * [Temperature Range Test](https://github.com/oresat/low-gain-radio/blob/master/docs/Test_Plan_Sputnik_Capstone.md#temperature-range-test) (For future designs)
     * [Vacuum Test](https://github.com/oresat/low-gain-radio/blob/master/docs/Test_Plan_Sputnik_Capstone.md#vacuum-test) (For future designs)
* [System Tests](https://github.com/oresat/low-gain-radio/blob/master/docs/Test_Plan_Sputnik_Capstone.md#system-tests)
    * [Radio Communication Test](https://github.com/oresat/low-gain-radio/blob/master/docs/Test_Plan_Sputnik_Capstone.md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)
    * [Control Test](https://github.com/oresat/low-gain-radio/blob/master/docs/Test_Plan_Sputnik_Capstone.md#control-test)
    * [Command Test](https://github.com/oresat/low-gain-radio/blob/master/docs/Test_Plan_Sputnik_Capstone.md#command-test)
    * [Functionality Test](https://github.com/oresat/low-gain-radio/blob/master/docs/Test_Plan_Sputnik_Capstone.md#functionality-test)

### Revision History

03/03/16 - Created document (Shan)

03/04/16 - Converted to markdown, proofreading changes (Will)

04/17/16 - Changed Communications Test, added functionalty test and grid, added Command test, changed incorrect links in ToC (Jake)

04/17/16 - Added component test section and all component tests and grids: Crystal, supply range, temperature, force, and vacuum. (Jake) 

04/20/16 - Fixed ToC link error (Jake)

04/21/16 - Moved to oresat repo and fixed ToC links (Jake)

04/29/16 - Changes based on Test Plan Review (Jake)

04/29/16 - Changes based on proofreading the test plan (Will)

04/30/16 - More proofreading changes. Changed crystal test to make it explicit that it will be performed on BOTH microcontrollers. Changed Supply Range Test to encompass BOTH modules. Changed Temperature Range Test to encompass BOTH modules and changed steps, actions, and expected results. Revised Acceleration test.

05/14/16 - Grammar corrections in introduction.

05/16/16 - Removed "Test Setup and Calibration" section from the document. Revised Temperature Test with updated procedure. (Shan)  

06/01/16 - Added test results for some of the tests (Jake)  

06/05/16 - More updated test results (Jake)  

06/08/16 - Removed untested tests (Jake)

06/09/16 - Added final test results (Jake)  

06/09/16 - Added Control test results (Jake)

### Introduction

#### Purpose

The purpose of this document is to outline testing that will be essential for determining the effectiveness of the Sputnik Capstone project. This test plan is not intended to be all inclusive and additional testing procedures will be added if deemed necessary by any of the parties involved in the project.

#### Testing Procedure

All of the testing procedures described in this document will be carried out by one or more of the Sputnik capstone team members. An effort will be made to have the entire team present for as many of the tests as possible.

#### Recordings of Results, Witnessing, and Authorities

The results of all testing will be posted in [this git respository](https://github.com/oresat/low-gain-radio) in the docs folder. The tests will be conducted on a pass/fail basis and any tests that do not pass will be noted along with an explanation/conjecture as to why they did not pass. No authorities or witnesses outside of the group will be required to be present during testing.

### Reference Documents

#### Design Documentation

Phase 1 Low Level Diagram

The Sputnik Capstone project is composed of two separate modules: The low-gain-radio (LGR) module and the system-controller (SysCon) module. The LGR is contains a microcontroller with an integrated transceiver referred to as the KW0x that facilitates wireless communication. The SysCon contains a radiation hardened watchdog controller that will be responsible for power cycling components after [Single-Event Upsets](https://en.wikipedia.org/wiki/Single_event_upset) happen. It will also contain only radiation hardened parts to ensure that its power domain is secure. However, for this project, the radiation-hardened components will be replaced with off-the shelf components to help reduce cost.

### Overview

#### Operational Description

The Portland State Aerospace Society is sponsoring this capstone based on the need for a command, control, and communications system for their CubeSat project. The focus of this project will be rapidly prototyping the LGR and SysCon which compose what is referred to as [Sputnik](https://en.wikipedia.org/wiki/Sputnik_1) because of it's requirements to be a simple, reliable space system. Sputnik will be responsible for long distance communications to and from earth while the CubeSat is in orbit, as well as, controlling and communicating with a payload that is housed within the CubeSat. On top of fulfilling these duties, once space bound, it will need to be able to deal with a temperature range of -40C to 80C and radiation events that could cause components to latch up.

### Pre-test preparation

#### Test equipment

The equipment needed for the tests is as follows: 
* Power Supply
    * Able to supply a minimum current of 1A at 3V for approximately 15 minutes
* Multimeter
* Oscilloscope
* Programmers for KW0x and ATMega128
* Environmental Chamber
* Vacuum Chamber
* Antennas

### Component Tests

The Component Tests will test components that are imperative to the core operation of integrated circuits (microcontrollers, voltage regulators, etc.) that implement the desired functionality for the module they are a part of. These are usually small simple tests that ensure that everything is working properly before attempting any tests for functionality.

#### Supply Range Test

The Supply Range Test is for testing the voltage range operation of the LGR and SysCon. This is needed since both modules will be receiving a range of voltages from 3-5V from the power management system (another module in the CubeSat). This test will be done by gradually changing the output voltage on the power supply from 3V-5V and checking that the board still operates. This test also doubles as a test for the crystal, since by checking the crystal we can ensure that the MCU on either board is on.

                          |                              |
------------------------- | ---------------------------- |
Test Case Name            | Supply Range Test            |
Test ID#                  | Supply_1.00                  |
Test Writer               | James Heath, Will Harrington | 
Description               | The purpose of this test is to demonstrate the functionality of the boards and their crystals at the required supply range limits. |
Tester Information        |    |
Name of Tester            |  James Heath (LGR), Shan Quinney & Michael Mathis (SC)  |
Time/Date                 |  5/29/2016, 5/29/2016  |
Hardware Version          |  LGR1.00, SC1.00  |
Setup                     |  Oscilloscope and Power supply in LID  |

Step | Action | Expected Result | Pass/Fail | Comments |
---- | ------ | --------------- | --------- | -------- |
1 | Set voltage supply to 3.0V for LGR | Power LEDs light up (LED1, LED4 on LGR schematic)  | PASS | 3.0V at 3.0V supply |
2 | Check that XTAL is operating with oscillscope | Desired frequency is shown on oscilloscope  | PASS | 32 MHz |
3 | Set voltage supply to 5V for LGR | Power LEDs light up (LED1, LED4 on LGR schematic)  | PASS | 3.3V at 5.0V supply |
4 | Check that XTAL is operating with oscillscope | Desired frequency is shown on oscilloscope  | PASS | 32 MHz |
5 | Set voltage supply to 3.0V for SysCon | Measure V+ at 3.3V with multimeter  | PASS | 3.0 V at 3.0 V supply |
6 | Check that XTAL is operating with oscillscope | Desired frequency is shown on oscilloscope  | PASS | 8 MHz |
7 | Set voltage supply to 5V for SysCon | Measure V+ at 5V with multimeter  | PASS | 3.3V at 5.0V supply. |
8 | Check that XTAL is operating with oscillscope | Desired frequency is shown on oscilloscope  | PASS | 8 MHz |  

### System Tests

#### Radio Test

The purpose of this test is to confirm that the radio is capable of transmission and reception, as well as switching between the Tx and Rx lines. This test will be performed by sending a carrier signal from one board to the other and lighting an LED when receiving the signal. The test locations will be predetermined based on both convenience and also where the least restricted signal propagation path will occur.

                          |                              |
------------------------- | ---------------------------- |
Test Case Name            | Radio Communication          |
Test ID#                  | RadCom_1.00                  |
Test Writer               | Shan Quinney/James Heath     | 
Description               | The purpose of this test is to ensure that the radio is capable of transmitting and receiving signals. |
Tester Information        |    |
Name of Tester            |  James Heath, Shan Quinney   |
Time/Date                 |  6/6/2016  |
Hardware Version          |  Sputnik radio board version 1.00  |
Setup                     | Have boards at some short distance apart. Each location will have a Sputnik radio board with sufficient power supply. Each location will also have a method to verify sent payload data.   |

Step | Action | Expected Result | Pass/Fail | Comments |
---- | ------ | --------------- | --------- | -------- |
1 | Board A is made to transmit carrier signal. | Board B confirms receiving signal from board A by ouputting payload to terminal via UART.  | PASS | 0x01 0x23 0x45 0x67 0x89 appears on terminal  |
2 | Board B is made to transmit carrier signal. | Board A confirms receiving signal from board B by ouputting payload to terminal via UART.   | PASS | 0x01 0x23 0x45 0x67 0x89 appears on terminal |

**Overall Test Result:** Success  

#### Control Test

The system controller is the guardian of the system. It is present to ensure that the system is functioning correctly and that if any unintended event causes component latch-up or system errors, the system can be cycled or rebooted to return stability. This control system is the other half of the project. Eventually, this system will consist of a radiation hardened microcontroller (ATMegaS128) with supporting radiation hardened LDO. For the purpose of prototyping, the controller is a standard, off-the-shelf ATMega128 chip.

To test the control system, a method to simulate a latch-up event will be used to trigger the watchdog into action. Outlined is the kw0x lock-up test. In this test, the crystal on the kw0x will be shorted to cause an error in the radio system. The ATMega should sense that the radio is no longer functioning properly and trigger the reset line on the kw0x to initiate a reboot.

                          |                              |
------------------------- | ---------------------------- |
Test Case Name            | Control Test       |
Test ID#                  | ATM_1.00                     |
Test Writer               | Shan Quinney, Michael Mathis         | 
Description               | The purpose of this test is to demonstrate the effectiveness of the system controller to restart key systems when UART "I'm alive" signals are lost. |
Tester Information        |    |
Name of Tester            |  Michael Mathis  |
Time/Date                 |  6/1/2016  |
Hardware Version          |  Board Rev.1, Filter Rev.1 |
Setup                     |  Laptop and portable programmer  |

Step | Action | Expected Result | Pass/Fail | Comments |
---- | ------ | --------------- | --------- | -------- |
1 | Remove the wire connecting the system controller UART rx and the LGR tx | The system controller will loose the signal from the LGR.  | PASS | Signal is lost |
2 | Probe the UART line between the controller and the LGR to determine that the life line signal is lost | The UART line will be free of any signal between the LGR and the controller.  | PASS | No signal detected |
3 | Monitor the controller to ensure that the reset line on the kw0x has been activated | The reset line on the kw0x will be activated in an effort to reboot the device.  | PASS | Reset line is active |
4 | After 4 seconds make sure that the "I'm alive" signal from the LGR is found again  | The system controller will be receiving the life line signal from the LGR   | PASS |  LGR is restarted and signaling again  |

**Overall Test Result:** Success  

#### Command Test

The Command Test helps us understand whether the board is able to issue commands and update or respond based on these commands. To test this, the Microcontroller will send a command to an LED to light up. If the LED lights up, then the command was successful indicating that the board is able to issue commands.

                          |                              |
------------------------- | ---------------------------- |
Test Case Name            | Command Test                 |
Test ID#                  | CMD_1.00                     |
Test Writer               | Will Harrington              | 
Description               | The purpose of this test is to demonstrate the effectiveness of the system controller to execute commands |
Tester Information        |    |
Name of Tester            |  Michael Mathis & Shan Quinney  |
Time/Date                 |  6/2/2016  |
Hardware Version          |  SC1.00  |
Setup                     |  Sent commands across JTAG interface, viewed LEDs for results |

Step | Action | Expected Result | Pass/Fail | Comments |
---- | ------ | --------------- | --------- | -------- |
1 | Send command | Successful send  | PASS | LED successfully lights up indicating the signal was sent |
2 | Observe LED on prototype | LED lights up  | PASS | LED successfully lights up |

**Overall Test Result:** Success  

#### Functionality Test

                          |                              |
------------------------- | ---------------------------- |
Test Case Name            | Functionality Test           |
Test ID#                  | Func_1.00                    |
Test Writer               | James Heath, Will Harrington | 
Description               | The purpose of this test is to observe the desired functionality as outlined in the project requirements of the LGR and SysCon. |
Tester Information        | The test needs to be performed over a distance of at least 10km. Two LGR setups will be needed we refer to them as Board Tx and Board Rx. By configure Board TX, we mean that it is to send a command to the other module that will cause it to output desired payload. By configure Setup X for RX, we mean that it is to listen for a command that will cause it to output the payload on a computer terminal via UART.  |
Name of Tester            |  Full team  |
Time/Date                 |  6/9/2016  |
Hardware Version          |  LGR1.00, SC1.00  |
Setup                     | Directional Antennas, Power supply, Test sites that are 10km a part   |

Step | Action | Expected Result | Pass/Fail | Comments |
---- | ------ | --------------- | --------- | -------- |
1 | Record GPS coordinates of Setup A and Setup B. Use Coordinate Distance Calculator to get distance.  | Distance is at least 10km  | PASS | Distance around 10.57km from OHSU to Rocky Butte |
2 | Tx Board transmits packet at high power. | High Power LED lights up, terminal reading from UART indicates 0 dBm output from kw0x  | PASS | LED lit up and terminal indicated 0 dBm |
3 | Rx Board receives and outputs to terminal via UART. | Terminal reads payload  | PASS | Terminal read payload: 0x01 0x23 0x45 0x67 0x89 |

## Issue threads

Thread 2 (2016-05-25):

Do not connect DIO0 to RESET(RF)

andrewgreenberg, 2016-05-25:
v1.2 of the LGR has DIO0 connected to RESET(RF). Turns out DIO0's default configuration is to go high when a packet is transmitted, which means the whole transceiver is reset when a packet is sent.

Whoops. :/

In the future, don't do this. Use a regular GPIO pin.

Bearking, 2016-07-04:
Connected now to PTE16.

Closed 2016-07-04.

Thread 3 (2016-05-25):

32 MHz crystal needs ground connection

andrewgreenberg, 2016-05-25:
- Add a pin on the schematic symbol for the two pads and the case.
- Connect the pads and case to ground.
- Not critical for functionality, but good practice.

Bearking, 2016-07-05:
Done and done

Closed 2016-07-05.

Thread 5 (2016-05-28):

Inverter for RF switch (NC7SZ05) output

wrh2, 2016-05-28:
The selected inverter for the RF switch has high impedance open-drain output when input is low which means the RF switch doesn't switch to the LNA for RX. We've modwired a pull-up resistor for now but this component should be replaced.

andrewgreenberg, 2016-06-01:
That said, because of available voltages and the switching voltage into the RXTX switch.

Bearking, 2016-07-01:
We'll probably get rid of the current switch and use one that doesn't require an inverter so I'm closing this.

Closed 2016-07-01.

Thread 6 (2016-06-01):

Get a new RXTX switch

andrewgreenberg, 2016-06-01:
... one that can accept a control voltage that isn't "3.0V" but can accept a wider range, like 3.3 or even V+. Also, maybe one that doesn't blow up at 5V.

Bearking, 2016-07-01:
http://www.psemi.com/pdf/datasheets/pe42723ds.pdf.

This is my suggested switch. Works at our frequency and has similar characteristics to the SkyWorks part. Also has the correct footprint and allows up to 3.6 V for the VCNT pin.

wrh2, 2016-10-04:
http://www.rfmd.com/store/downloads/dl/file/id/28477/rf3025_data_sheet.pdf

Ended up going with this for the new rev.

Closed 2016-10-04.

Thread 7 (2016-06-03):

Magic numbers in transceiver driver

wrh2, 2016-06-03:
We've been changing a lot of things in the transceiver configuration part of the transceiver driver lately as part of an effort to get RX/TX to work. In that process lots of magic numbers have appeared. We need to define them so people can understand our driver.

Bearking, 2016-07-01:
I believe Theo and Kay have fixed this

Closed 2016-07-01.

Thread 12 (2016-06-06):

All LEDs need much larger resistors, like 10k, in order not to blind us.

andrewgreenberg, 2016-06-06:

Bearking, 2016-07-04:
This is only true for Shan's LEDs. I ran out so I started using his. They aren't blinding when using the ones I originally had chosen.

Closed 2016-07-04.

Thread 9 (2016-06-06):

LGR ought to have LEDs on the UART0 TX/RX lines

andrewgreenberg, 2016-06-06:
.. because debugging. Why does no one make an LED with built in driving buffers? Why isn't this a thing? It's brilliant.

Bearking, 2016-07-04:
Added for rev 2

Closed 2016-07-04.

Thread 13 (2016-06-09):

Replace MACOM LNA with Skyworks

Bearking, 2016-06-09:
Skyworks has actual data and likely better results in the band we are looking at, despite more complicated circuitry.

Bearking, 2016-07-01:
Maybe talk to Glenn to see if this is even necessary? Is there a way to test if the noise figure is good enough?

Bearking, 2016-07-04:
We probably don't even need to look at the NF as long as there is good enough amplification.

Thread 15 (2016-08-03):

Modwire 3 v1_2 boards for DIO connected to Transceiver reset issue

kwilsonpdx, 2016-08-03:
On the v1_2 boards the SPI status line was connected to the Transceiver reset by mistake. We can fix this then keep playing with the SPI interface software.

kwilsonpdx, 2016-08-03:
* Board A modwire complete and passes test.
* Board B failed test
* Board C awaiting modwire

andrewgreenberg, 2016-10-10:
I'm closing this because we're moving on to v2_0.

Closed 2016-10-10.

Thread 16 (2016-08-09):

Proposal: set v1_2 as default branch on github

kwilsonpdx, 2016-08-09:
Since we decided (***for now***) to have one branch per hardware version and v1_2 is the latest version of the LGR, I thought we could change to v1_2 as default branch for cloning etc.

Thoughts?
  -K

natronics, 2016-08-09:
There are a couple of ways to go about it:

one is to have `master

kwilsonpdx, 2016-08-18:
Switched the default branch to v1_2

wrh2, 2016-10-10:
We just finished v2_0 so that needs to be set as the default branch. Furthermore, the default branch needs to get switched every time we do a board rev so I feel like this should be the responsibility of Andrew, Jake, or myself.

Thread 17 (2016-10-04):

Listen mode MCU clock signal loss during Idle period

wrh2, 2016-10-04:
From the MKW01Z128 reference manual: "In Idle mode (a phase of Listen mode), the 32 MHz crystal oscillator of the transceiver is disabled. If this signal, or a derivative thereof, is used as the MCU clock via CLKOUT to EXTAL0, care should be taken in firmware to configure the MCU clock to an internal low-power clock immediately prior to asserting Listen mode to prevent loss of clock affecting MCU performance."

This is not something I was aware of when I created the listen mode portion of the transceiver driver and I need to fix it to deal with this.

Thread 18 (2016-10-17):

DC blocking caps or critical filter components?

andrewgreenberg, 2016-10-17:
C14 and C25 look like DC blocking caps. They were 100nF and 10nF respectively, both of which are really too big for good 0402 RF performance at 500+ MHz. So I switched them to 100 pF. Is that OK?

On that note:

What about removing C23, C58 or C61? Do we need C61 to protect the radio? Can we just remove all of these caps?

glennl, 2016-10-17:
Yes, C14 and C25 sure look like DC blocks, and 100 pF seems fine. Go with it.

C23, C58, and C61 totally need to be there. They are blocking the DC associated with the PIN switch. They are all needed.

BTW, the insertion loss on the RF3025 is about 0.45 dB at 500 MHz. Sad.

Closed 2016-10-17.

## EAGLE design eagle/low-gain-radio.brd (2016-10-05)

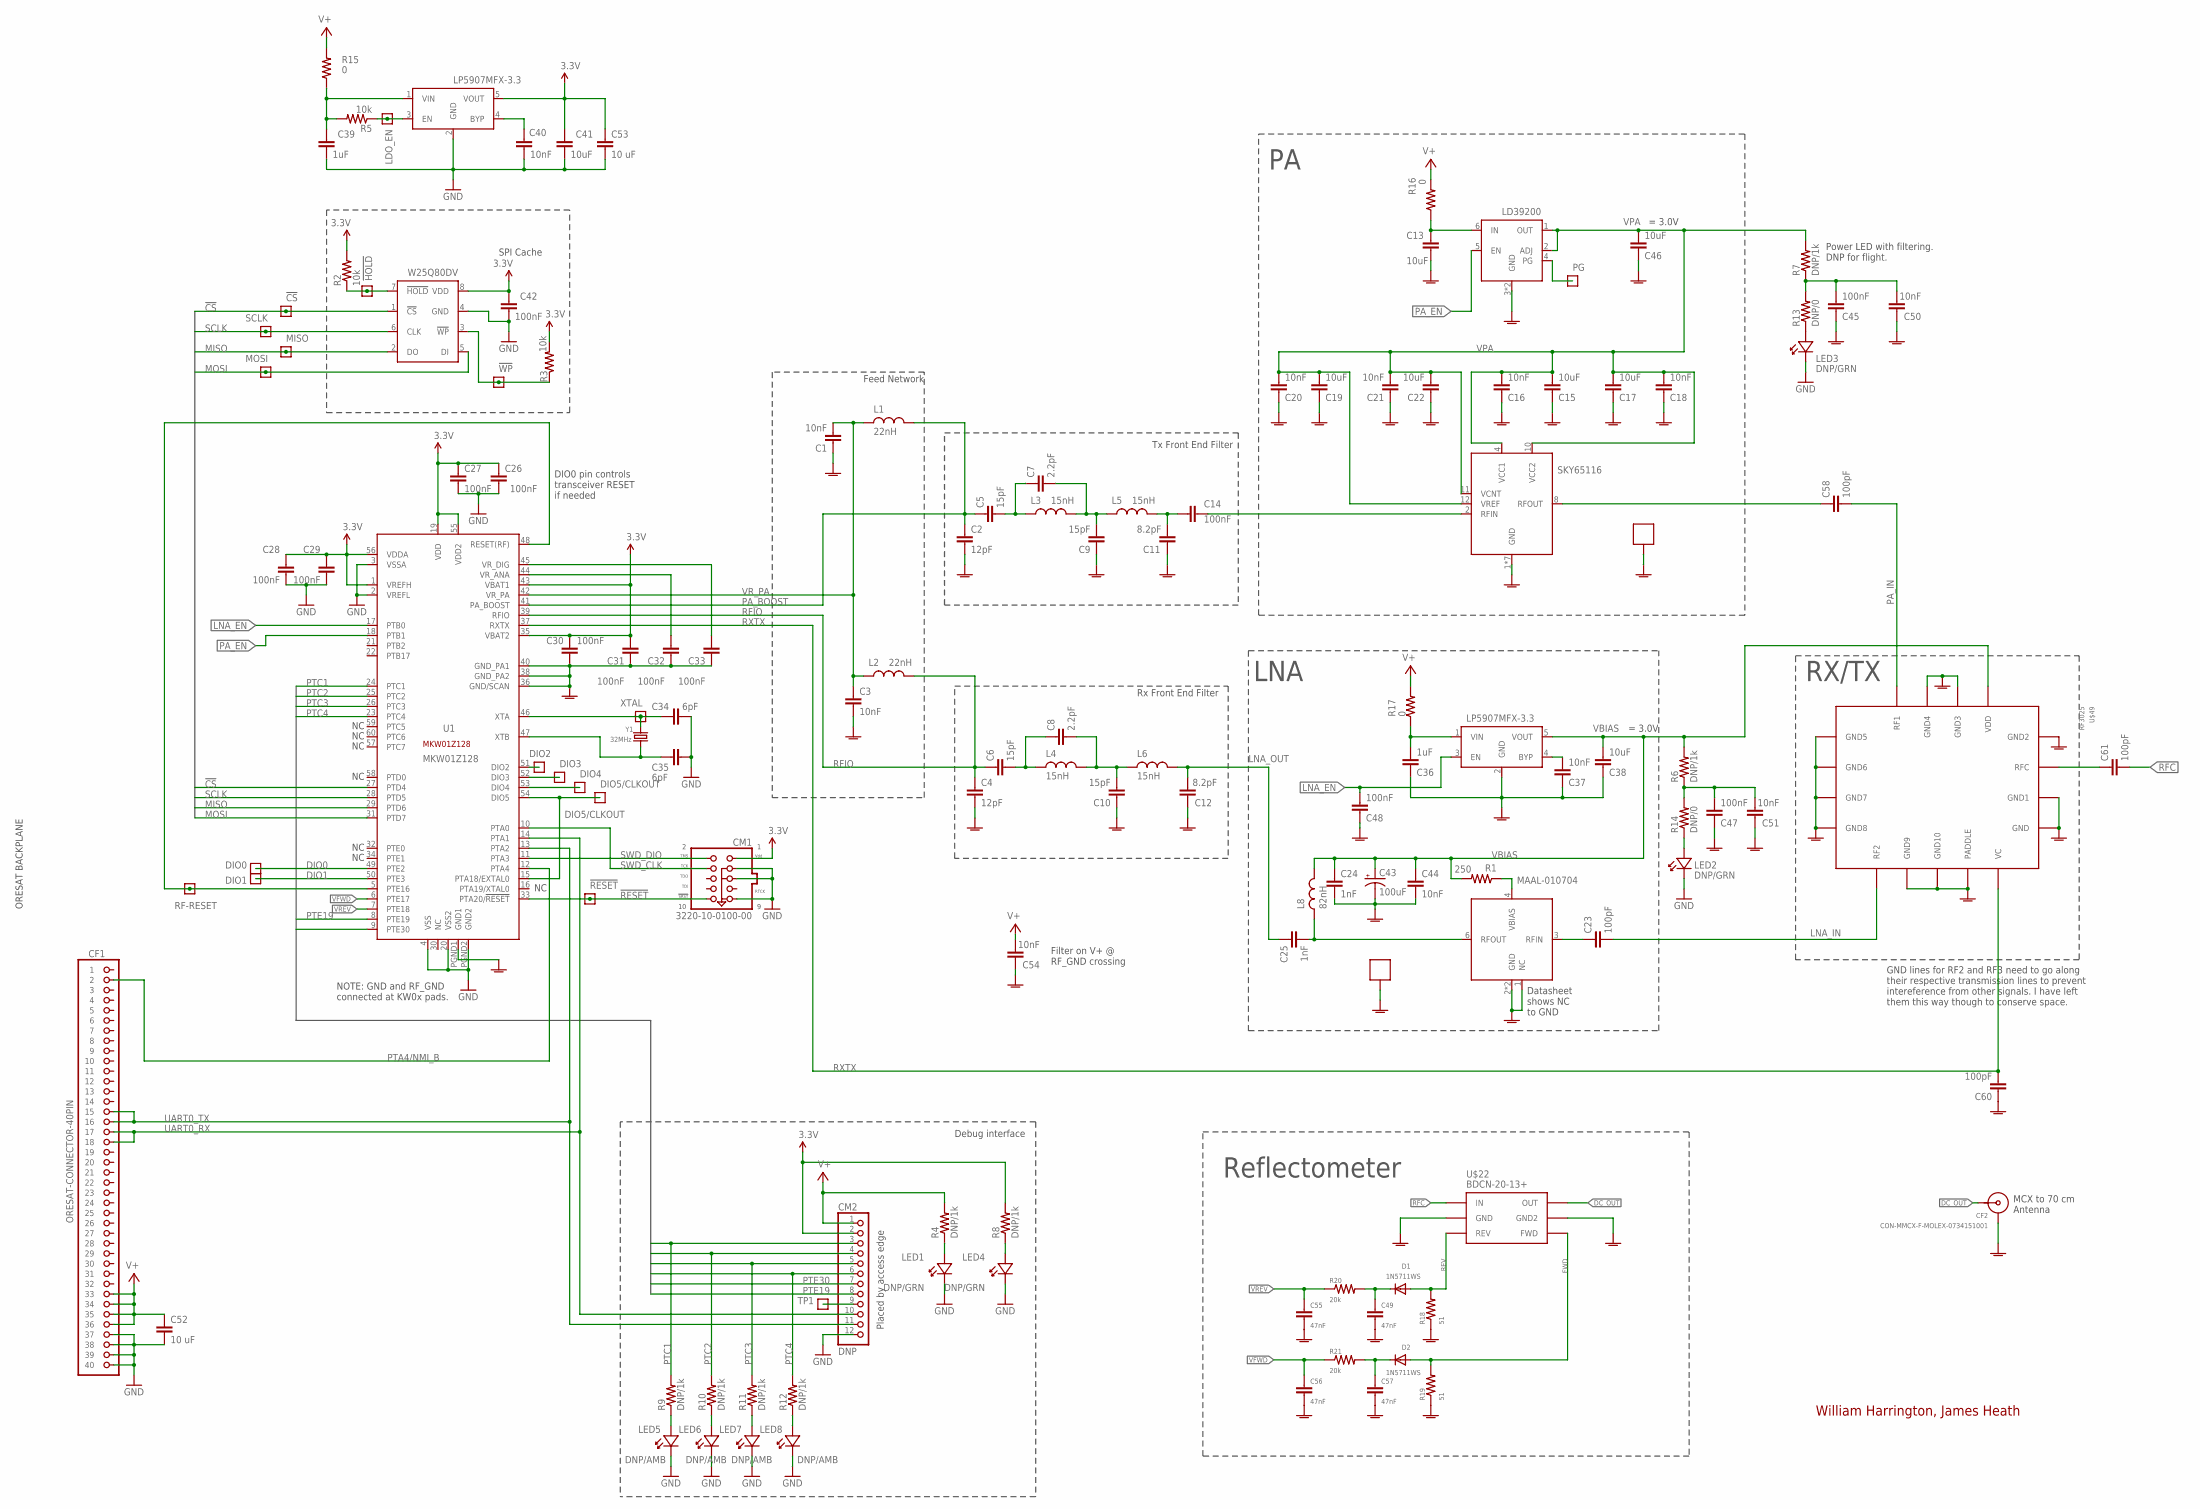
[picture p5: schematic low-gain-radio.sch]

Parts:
!CS: TEST-POINT; 2MM-TEST-POINT
!HOLD: TEST-POINT; 2MM-TEST-POINT
!RESET: TEST-POINT; 2MM-TEST-POINT
!WP: TEST-POINT; 2MM-TEST-POINT
C1, C3, C16, C18, C20, C21, C37, C40: 10nF; .0603-B-NOSILK; MFG_PN GRM188R71H103KA01D
C2, C4: 12pF; .0603-B-NOSILK; MFG_PN GRM1885C1H120JA01D
C5, C6, C9, C10: 15pF; .0603-B-NOSILK; MFG_PN GRM1885C1H150JA01D
C7, C8: 2.2pF; .0603-B-NOSILK; MFG_PN GRM1885C1H2R2CA01D
C11, C12: 8.2pF; .0603-B-NOSILK; MFG_PN 06031U8R2BAT2A
C13, C15, C17, C19, C22, C38, C41, C46: 10uF; .0603-B-NOSILK; MFG_PN GRM188R60J106ME47J
C14, C26, C27, C28, C29, C30, C31, C32, C33, C42, C45, C47, C48: 100nF; .0603-B-NOSILK; MFG_PN 06035C104JAT2A
C23, C58, C60, C61: 100pF; .0402-C-NOSILK; MPN CBR04C101F3GAC
C24, C25: 1nF; .0402-B-NOSILK; MFG_PN GRM155R71H102KA01D
C34, C35: 6pF; .0603-B-NOSILK; MFG_PN GQM1875C2E6R0BB12D
C36, C39: 1uF; .0603-B-NOSILK; MFG_PN GRM188R61A105KA61D
C43: 100uF; CT6032; MFG_PN TAJC107K010RNJ
C44: 10nF; .0402-B-NOSILK; MFG_PN GRM155R71H103KA88D
C49, C55, C56, C57: 47nF; .0402-C-NOSILK; MPN LMK105SD472KV-F
C50, C51, C54: 10nF; .0402-B-NOSILK; MFG_PN GRM155R71H102KA01D
C52: 10 uF; .0805-B-NOSILK
C53: 10 uF; .0805-B-NOSILK; MFG_PN GRM188R60J106ME47J
CF1: ORESAT-CONNECTOR-40PIN; HARWIN-ARCHER-M50-3202045
CF2: CON-MMCX-F-MOLEX-0734151001
CM1: 3220-10-0100-00; PINHEADER-2X5-0.05+POL+SILK; MFG_PN 3220-10-0100-00
CM2: DNP; 1X12
D1, D2: 1N5711WS; SOD-323; MPN 1N5711WS
DIO0, DIO1, DIO2, DIO3, DIO4, DIO5/CLKOUT: TEST-POINT; 2MM-TEST-POINT
L1, L2: 22nH; .0603-B-NOSILK@1; MFG_PN LQW18AN22NG00D
L3, L4, L5, L6: 15nH; .0603-B-NOSILK@1; MFG_PN LQW18AN15NG00D
L8: 82nH; .0603-B-NOSILK@1; MFG_PN LQW18AN82NG00D
LDO_EN: TEST-POINT; 2MM-TEST-POINT
LED1, LED2, LED3, LED4: DNP/GRN; LED-0603; MFG_PN LTST-C191KGKT
LED5, LED6, LED7, LED8: DNP/AMB; LED-0603; MFG_PN LTST-C191AKT
MISO: TEST-POINT; 2MM-TEST-POINT
MOSI: TEST-POINT; 2MM-TEST-POINT
PG: TEST-POINT; 2MM-TEST-POINT
R1: 250; .0603-B-NOSILK@1; MFG_PN RC1608F2490CS
R2, R3, R5: 10k; .0603-B-NOSILK@1; MFG_PN RC0603FR-0710KL
R4, R6, R7, R8, R9, R10, R11, R12: DNP/1k; .0603-B-NOSILK@1; MFG_PN RC0603FR-071KL
R13, R14: DNP/0; .0603-B-NOSILK@1; MFG_PN RC0603JR-070RL
R15, R16, R17: 0; .0805-C-NOSILK$1; MPN RC0805JR-070RL
R18, R19: 51; .0402-C-NOSILK$1; MPN RC0402FR-0751RL
R20, R21: 20k; .0402-C-NOSILK$1; MPN RT0402BRD0721KL
RF-RESET: TEST-POINT; 2MM-TEST-POINT
SCLK: TEST-POINT; 2MM-TEST-POINT
SH1, SH2: BMI-S-202-SHIELD; BMI-S-202
TP1: TEST-POINT; 2MM-TEST-POINT
U1: MKW01Z128; MPN MKW01Z128CHN
U2: SKY65116
U3: W25Q80DV; MFG_PN W25Q80DVSSIG
U4, U6: LP5907MFX-3.3; SOT23-5
U7: LD39200; MFG_PN LD39200PU33R
U8: MAAL-010704; SOT-363
U$22: BDCN-20-13+; FV1206-1; MPN BDCN-20-13+
U$49: RF3025; QFN-16_3MMX3MM; MPN RF3025TR7
XTAL: TEST-POINT; 2MM-TEST-POINT
Y1: 32MHz; CRYSTAL_2.5X2; MPN FA20H 32.0000MF12Y-W3

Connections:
3.3V: C26.1, C27.1, C28.2, C29.2, C30.2, C31.2, C41.2, C42.2, C53.1, CM1.1 (VDD), CM2.2, R2.2, R3.2, R8.2, U1.1 (VREFH), U1.19 (VDD), U1.35 (VBAT2), U1.43 (VBAT1), U1.55 (VDD2), U1.56 (VDDA), U3.8 (VDD), U4.5 (VOUT)
!CS: !CS.1, U1.27 (PTD4), U3.1 (!CS)
!HOLD: !HOLD.1, R2.1, U3.7 (!HOLD)
!RESET: !RESET.1, CM1.10 (SRST), U1.33 (PTA20/!RESET)
!WP: !WP.1, R3.1, U3.3 (!WP)
BYPASS: C37.2, U6.4 (BYP)
DC_OUT: CF2.CENTER, U$22.OUT
DIO0: DIO0.1, U1.49 (PTE2)
DIO1: DIO1.1, U1.50 (PTE3)
DIO2: DIO2.1, U1.51 (DIO2)
DIO3: DIO3.1, U1.52 (DIO3)
DIO4: DIO4.1, U1.53 (DIO4)
DIO5/CLKOUT: DIO5/CLKOUT.1, U1.15 (PTA18/EXTAL0), U1.54 (DIO5)
FWD: D2.A, R19.2, U$22.FWD
GND: C26.2, C27.2, C28.1, C29.1, C34.1, C35.1, C39.1, C40.1, C41.1, C42.1, C52.2, C53.2, CF1.P$37 (37), CF1.P$38 (38), CF1.P$39 (39), CF1.P$40 (40), CM1.3 (GND3), CM1.5 (GND5), CM1.9 (GND9), CM2.12, LED1.K, LED2.K, LED3.K, LED4.K, LED5.K, LED6.K, LED7.K, LED8.K, U1.2 (VREFL), U1.3 (VSSA), U1.4 (VSS), U1.20 (VSS2), U1.PGND2 (GND2), U3.4 (GND), U4.2 (GND)
LDO_EN: LDO_EN.1, R5.1, U4.3 (EN)
LNA_EN: C48.2, U1.17 (PTB0), U6.3 (EN)
LNA_IN: C23.2, U$49.RF2
LNA_OUT: C12.2, C25.1, L6.2
MISO: MISO.1, U1.29 (PTD6), U3.2 (DO)
MOSI: MOSI.1, U1.31 (PTD7), U3.5 (DI)
unnamed: LED3.A, R13.1
unnamed: R1.1, U8.4 (VBIAS)
unnamed: LED2.A, R14.1
unnamed: PG.1, U7.4 (PG)
unnamed: CM2.9, TP1.1
unnamed: C13.2, R16.1, U7.6 (IN)
unnamed: C25.2, L8.1, U8.6 (RFOUT)
unnamed: C35.2, U1.47 (XTB), Y1.3 (2)
unnamed: C36.2, R17.1, U6.1 (VIN)
unnamed: C5.2, C7.1, L3.1
unnamed: C39.2, R5.2, R15.1, U4.1 (VIN)
unnamed: C40.2, U4.4 (BYP)
unnamed: LED1.A, R4.1
unnamed: LED5.A, R9.1
unnamed: C7.2, C9.2, L3.2, L5.1
unnamed: C11.2, C14.2, L5.2
unnamed: C6.2, C8.1, L4.1
unnamed: C8.2, C10.2, L4.2, L6.1
unnamed: LED6.A, R10.1
unnamed: LED7.A, R11.1
unnamed: LED4.A, R8.1
unnamed: LED8.A, R12.1
unnamed: C49.1, D1.C, R20.2
unnamed: C23.1, U8.3 (RFIN)
unnamed: C57.1, D2.C, R21.2
unnamed: C32.2, U1.44 (VR_ANA)
unnamed: C33.2, U1.45 (VR_DIG)
unnamed: C14.1, U2.2 (RFIN)
PA_BOOST: C2.1, C5.1, L1.2, U1.41 (PA_BOOST)
PA_EN: U1.18 (PTB1), U7.5 (EN)
PA_IN: C58.2, U$49.RF1
PTA4/NMI_B: CF1.P$2 (2), U1.12 (PTA4)
PTC1: CM2.3, R9.2, U1.24 (PTC1)
PTC2: CM2.4, R10.2, U1.25 (PTC2)
PTC3: CM2.5, R11.2, U1.26 (PTC3)
PTC4: CM2.6, R12.2, U1.23 (PTC4)
PTE19: CM2.8, U1.8 (PTE19)
PTE30: CM2.7, U1.9 (PTE30)
REV: D1.A, R18.2, U$22.REV
RFC: C61.2, U$22.IN
RFIO: C4.1, C6.1, L2.2, U1.39 (RFIO)
RFOUT: C58.1, U2.8 (RFOUT)
RF_GND: C1.1, C2.2, C3.2, C4.2, C9.1, C10.1, C11.1, C12.1, C13.1, C15.1, C16.1, C17.1, C18.1, C19.1, C20.1, C21.1, C22.1, C24.2, C30.1, C31.1, C32.1, C33.1, C36.1, C37.1, C38.1, C43.-, C44.2, C45.1, C46.1, C47.1, C48.1, C49.2, C50.1, C51.1, C54.1, C55.2, C56.2, C57.2, C60.1, CF2.G1 (SHIELD), CF2.G2 (SHIELD), CF2.G3 (SHIELD), CF2.G4 (SHIELD), R18.1, R19.1, SH1.P$1, SH1.P$2, SH1.P$3, SH1.P$4, SH1.P$5, SH1.P$6, SH1.P$7, SH1.P$8, SH1.P$9, SH1.P$10, SH1.P$11, SH1.P$12, SH2.P$1, SH2.P$2, SH2.P$3, SH2.P$4, SH2.P$5, SH2.P$6, SH2.P$7, SH2.P$8, SH2.P$9, SH2.P$10, SH2.P$11, SH2.P$12, U1.36 (GND/SCAN), U1.38 (GND_PA2), U1.40 (GND_PA1), U1.PGND1 (GND1), U2.1 (GND), U2.3 (GND), U2.5 (GND), U2.6 (GND), U2.7 (GND), U2.9 (GND), U2.CENTER (GND), U6.2 (GND), U7.3 (GND), U7.CENTER (GND), U8.1 (NC), U8.2 (GND), U8.5 (GND), U$22.GND, U$22.GND2, U$49.GND, U$49.GND1, U$49.GND2, U$49.GND3, U$49.GND4, U$49.GND5, U$49.GND6, U$49.GND7, U$49.GND8, U$49.GND9, U$49.GND10, U$49.PADDLE
RF_RESET: RF-RESET.1, U1.5 (PTE16), U1.48 (RESET(RF))
RXTX: C60.2, U1.37 (RXTX), U$49.VC
RXTX_OUT: C61.1, U$49.RFC
SCLK: SCLK.1, U1.28 (PTD5), U3.6 (CLK)
SWD_CLK: CM1.4 (TCK), U1.10 (PTA0)
SWD_DIO: CM1.2 (TMS), U1.11 (PTA3)
UART0_RX: CF1.P$17 (17), CF1.P$18 (18), CM2.10, U1.14 (PTA1)
UART0_TX: CF1.P$15 (15), CF1.P$16 (16), CM2.11, U1.13 (PTA2)
V+: C52.1, C54.2, CF1.P$33 (33), CF1.P$34 (34), CF1.P$35 (35), CF1.P$36 (36), CM2.1, R4.2, R15.2, R16.2, R17.2
VBIAS: C24.1, C38.2, C43.+, C44.1, L8.2, R1.2, R6.2, U6.5 (VOUT), U$49.VDD
VFWD: C56.1, R21.1, U1.6 (PTE17)
VPA: C15.2, C16.2, C17.2, C18.2, C19.2, C20.2, C21.2, C22.2, C46.2, R7.2, U2.4 (VCC1), U2.10 (VCC2), U2.11 (VCNT), U2.12 (VREF), U7.1 (OUT), U7.2 (ADJ)
VREV: C55.1, R20.1, U1.7 (PTE18)
VR_PA: C1.2, C3.1, L1.1, L2.1, U1.42 (VR_PA)
V_LNA_FILTERED: C47.2, C51.2, R6.1, R14.2
V_PA_FILTERED: C45.2, C50.2, R7.1, R13.2
XTA: C34.2, U1.46 (XTA), XTAL.1, Y1.1

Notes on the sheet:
William Harrington, James Heath
Feed Network
Tx Front End Filter
Rx Front End Filter
LNA
RX/TX
MCX to 70 cm Antenna
GND lines for RF2 and RF3 need to go along their respective transmission lines to prevent intereference from other signals. I have left them this way though to conserve space.
SPI Cache
Debug interface
Placed by access edge
ORESAT BACKPLANE
DIO0 pin controls transceiver RESET if needed
= 3.0V
Datasheet shows NC to GND
NOTE: GND and RF_GND connected at KW0x pads.
Power LED with filtering. DNP for flight.
Filter on V+ @ RF_GND crossing
Reflectometer

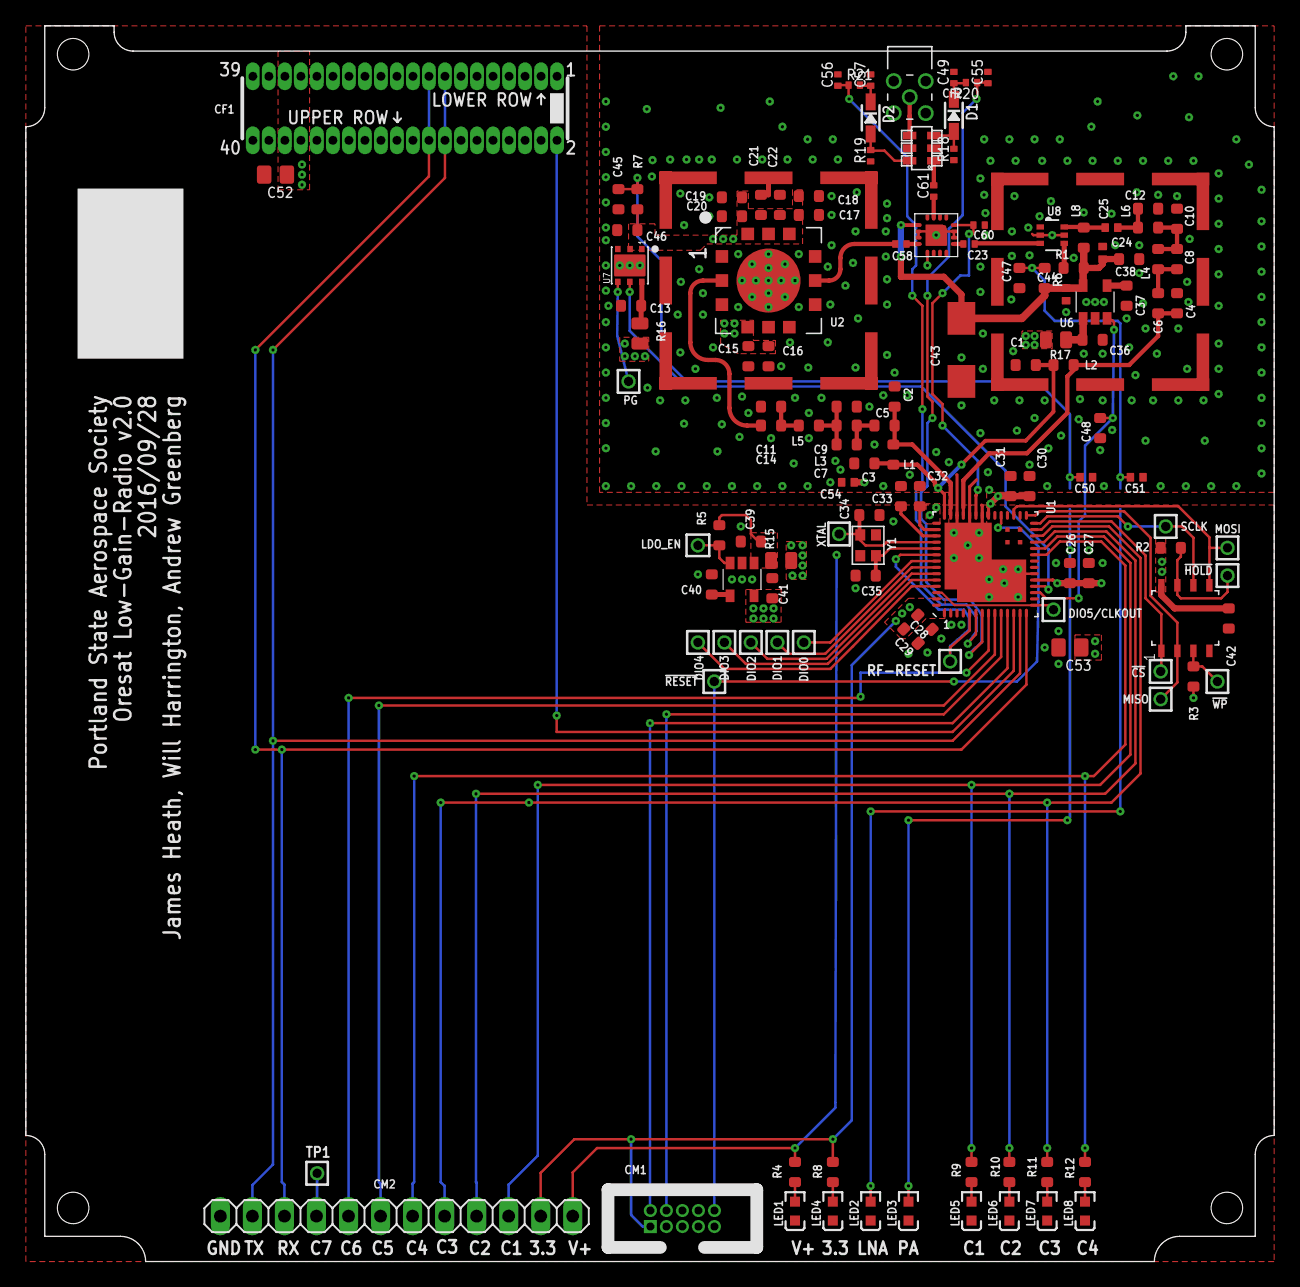
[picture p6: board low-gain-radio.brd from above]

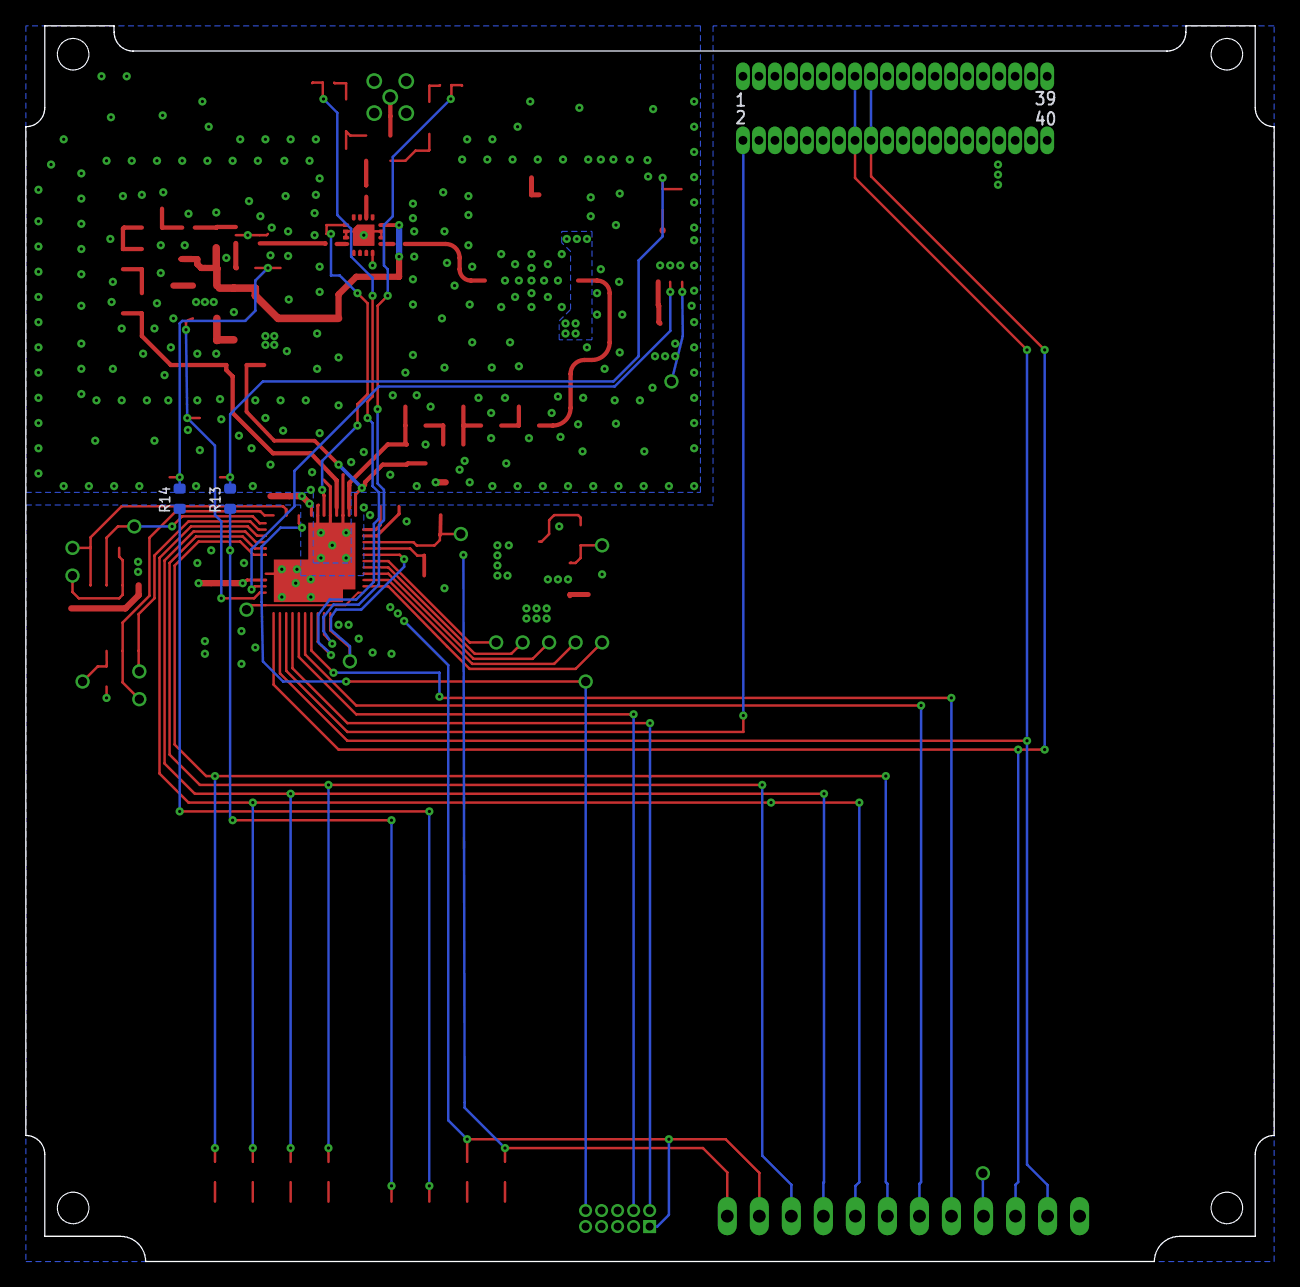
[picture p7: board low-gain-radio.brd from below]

Board: 4 copper layers, 99.0 x 98.0 mm, 133 parts (2 on the bottom side), 81 nets.

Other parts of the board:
U$35: ORESAT-CARD-V0.4

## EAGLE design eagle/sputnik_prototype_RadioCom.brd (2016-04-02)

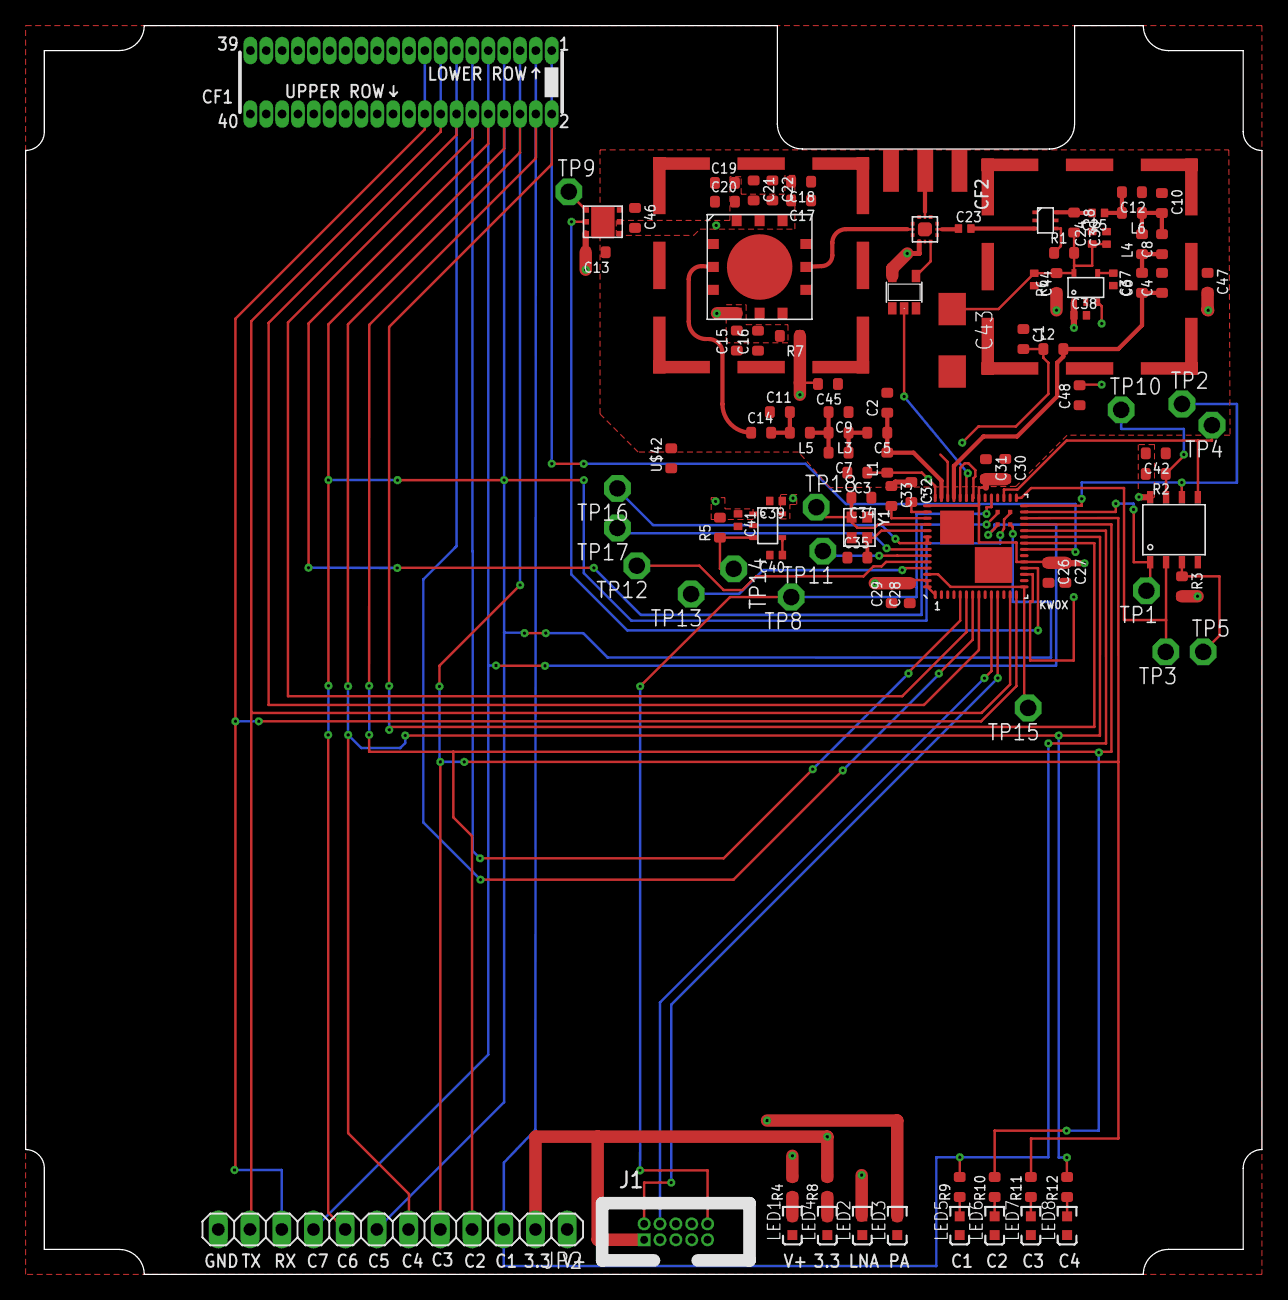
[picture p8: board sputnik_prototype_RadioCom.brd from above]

Board: 4 copper layers, 99.0 x 100.0 mm, 109 parts (0 on the bottom side), 73 nets.

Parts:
C1, C3, C16, C18, C20, C21: 10nF; .0603-B-NOSILK
C2, C4: 12pF; .0603-B-NOSILK
C5, C6, C9, C10: 15pF; .0603-B-NOSILK
C7, C8: 2.2pF; .0603-B-NOSILK
C11, C12: 8.2pF; .0603-B-NOSILK
C13, C15, C17, C19, C22, C46: 10uF; .0603-B-NOSILK
C14, C26, C27, C28, C29, C30, C31, C32, C33, C42, C45, C47, C48: 100nF; .0603-B-NOSILK
C23, C24, C25: 1nF; .0402-B-NOSILK
C34, C35: 6pF; .0603-B-NOSILK
C36, C39: 2.2uF; .0402-B-NOSILK
C37, C40, C44: 10nF; .0402-B-NOSILK
C38, C41: 1uF; .0402-B-NOSILK
C43: 100uF; CT6032
CF1: ORESAT-CONNECTOR-40PIN; HARWIN-ARCHER-M50-3202045
CF2: CON-MCX-LINX; CON-MCX-LINX-CONMCX003.062
J1: PINHEADER-2X5-0.05+POL+SILK
JP2: 1X12
KW0X: MKW01Z128
L1, L2: 22nH; .0603-B-NOSILK
L3, L4, L5, L6: 15nH; .0603-B-NOSILK
L8: 82nH; .0603-B-NOSILK
LED1, LED2, LED3, LED4, LED5, LED6, LED7, LED8: LED-0603
LNA: MAAL-010704
PA: SKY65116
R1: 250; .0603-B-NOSILK
R2, R3, R5: 10k; .0603-B-NOSILK
R4, R6, R7, R8, R9, R10, R11, R12: 1k; .0603-B-NOSILK
SH1, SH2: BMI-S-202-SHIELD; BMI-S-202
TP1, TP2, TP3, TP4, TP5, TP8, TP9, TP10, TP11, TP12, TP13, TP14, TP15, TP16, TP17, TP18: TPSPAD1-13; P1-13
TRSWITCH: SKY13405-490LF
U$1: W25Q80DV
U$7, U$8: AAT3215
U$9: LD39200
U$35: ORESAT-CARD-RF-V0.3
U$39: NC7SZ05
U$42: 742792651; .0603-B-NOSILK
Y1: 32MHz; CRYSTAL_2.5X2

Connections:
3.3V: C26.1, C27.1, C28.2, C29.2, C30.2, C31.2, C39.1, C42.2, J1.1, JP2.2, KW0X.1, KW0X.19, KW0X.35, KW0X.43, KW0X.55, KW0X.56, R2.2, R3.2, R8.2, U$1.8, U$8.5
!CS: KW0X.27, TP1.TP, U$1.1
!HOLD: R2.1, TP10.TP, U$1.7
!RESET: J1.10, KW0X.33, TP8.TP
DIO0: KW0X.48, KW0X.49, TP16.TP
DIO1: KW0X.50, TP17.TP
DIO5/CLKOUT: KW0X.15, KW0X.54, TP15.TP
GND: C26.2, C27.2, C28.1, C29.1, C34.1, C35.1, C36.2, C37.2, C38.2, C39.2, C40.2, C41.2, C42.1, C48.1, CF1.P$37, CF1.P$38, CF1.P$39, CF1.P$40, J1.3, J1.5, J1.9, JP2.12, KW0X.2, KW0X.3, KW0X.4, KW0X.20, KW0X.PGND1, KW0X.PGND2, LED1.K, LED2.K, LED3.K, LED4.K, LED5.K, LED6.K, LED7.K, LED8.K, LNA.1, TRSWITCH.11, U$1.4, U$7.2, U$8.2, U$42.1
LNA_EN: C48.2, KW0X.17, U$7.3
LNA_IN: C23.1, TRSWITCH.2
LNA_OUT: C12.2, C25.1, L6.2
MISO: KW0X.29, TP3.TP, U$1.2
MOSI: KW0X.31, TP4.TP, U$1.5
unnamed: C37.1, U$7.4
unnamed: TRSWITCH.12, U$39.4
unnamed: KW0X.51, TP11.TP
unnamed: TP9.TP, U$9.4
unnamed: KW0X.52, TP12.TP
unnamed: C34.2, KW0X.46, TP18.TP, Y1.1
unnamed: C25.2, L8.1, LNA.6
unnamed: C35.2, KW0X.47, Y1.3
unnamed: KW0X.53, TP13.TP
unnamed: C5.2, C7.1, L3.1
unnamed: R3.1, TP5.TP, U$1.3
unnamed: R5.1, TP14.TP, U$8.3
unnamed: C40.1, U$8.4
unnamed: LED1.A, R4.1
unnamed: LED5.A, R9.1
unnamed: C7.2, C9.2, L3.2, L5.1
unnamed: C11.2, C14.2, L5.2
unnamed: C6.2, C8.1, L4.1
unnamed: C8.2, C10.2, L4.2, L6.1
unnamed: LED6.A, R10.1
unnamed: LED7.A, R11.1
unnamed: LED4.A, R8.1
unnamed: LED8.A, R12.1
unnamed: C23.2, LNA.3
unnamed: LNA.4, R1.1
unnamed: CF2.CENTER, TRSWITCH.5
unnamed: C32.2, KW0X.44
unnamed: C33.2, KW0X.45
unnamed: C14.1, PA.2
PA_BOOST: C2.1, C5.1, KW0X.41, L1.2
PA_EN: KW0X.18, U$9.5
PA_IN: PA.8, TRSWITCH.8
PTB2: CF1.P$1, KW0X.21
PTB17: CF1.P$2, KW0X.22
PTC1: CF1.P$3, JP2.3, KW0X.24, R9.2
PTC2: CF1.P$4, JP2.4, KW0X.25, R10.2
PTC3: CF1.P$5, JP2.5, KW0X.26, R11.2
PTC4: CF1.P$6, JP2.6, KW0X.23, R12.2
PTC5: CF1.P$7, JP2.7, KW0X.59
PTC6: CF1.P$8, JP2.8, KW0X.60
PTC7: CF1.P$9, JP2.9, KW0X.57
PTD0: CF1.P$10, KW0X.58
PTE16: CF1.P$11, KW0X.5
PTE17: CF1.P$12, KW0X.6
PTE18: CF1.P$13, KW0X.7
PTE19: CF1.P$14, KW0X.8
RFIO: C4.1, C6.1, KW0X.39, L2.2
RF_GND: C1.1, C2.2, C3.2, C4.2, C9.1, C10.1, C11.1, C12.1, C13.1, C15.1, C16.1, C17.1, C18.1, C19.1, C20.1, C21.1, C22.1, C24.2, C30.1, C31.1, C32.1, C33.1, C43.-, C44.2, C45.1, C46.1, KW0X.36, KW0X.38, KW0X.40, LNA.2, LNA.5, PA.1, PA.3, PA.5, PA.6, PA.7, PA.9, SH1.P$1, SH1.P$2, SH1.P$3, SH1.P$4, SH1.P$5, SH1.P$6, SH1.P$7, SH1.P$8, SH1.P$9, SH1.P$10, SH1.P$11, SH1.P$12, SH2.P$1, SH2.P$2, SH2.P$3, SH2.P$4, SH2.P$5, SH2.P$6, SH2.P$7, SH2.P$8, SH2.P$9, SH2.P$10, SH2.P$11, SH2.P$12, TRSWITCH.1, TRSWITCH.3, TRSWITCH.4, TRSWITCH.6, TRSWITCH.7, TRSWITCH.9, U$9.3, U$39.3, U$42.2
RXTX: KW0X.37, U$39.2
SCLK: KW0X.28, TP2.TP, U$1.6
SWD_CLK: J1.4, KW0X.10
SWD_DIO: J1.2, KW0X.11
UART0_RX: CF1.P$17, CF1.P$18, JP2.10, KW0X.14
UART0_TX: CF1.P$15, CF1.P$16, JP2.11, KW0X.13
V+: C13.2, C38.1, C41.1, CF1.P$33, CF1.P$34, CF1.P$35, CF1.P$36, JP2.1, R4.2, R5.2, TRSWITCH.10, U$7.1, U$8.1, U$9.6, U$39.5
VBIAS: C24.1, C36.1, C43.+, C44.1, L8.2, R1.2, R6.2, U$7.5
VPA: C15.2, C16.2, C17.2, C18.2, C19.2, C20.2, C21.2, C22.2, C46.2, PA.4, PA.10, PA.11, PA.12, R7.2, U$9.1, U$9.2
VR_PA: C1.2, C3.1, KW0X.42, L1.1, L2.1
V_LNA_FILTERED: C47.2, LED2.A, R6.1
V_PA_FILTERED: C45.2, LED3.A, R7.1

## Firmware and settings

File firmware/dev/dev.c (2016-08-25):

/* \file dev.c
 * Low Gain Radio firmware
 */

#include <string.h>

#include "v1_2.h"

#include "lgr_vector.h"

#include "core_cm0plus.h"
#include "cmsis_gcc.h"

#include "lgr_util.h"
#include "port.h"
#include "clocks.h"
#include "led.h"
#include "uart.h"
#include "spi.h"
#include "xcvr.h"
#include "ringbuffer.h"
#include "em-printf.h"

#include "dev.h"

struct spi_config spi0_config =
{
	.SCK        = {.port = &PORTC, .pin = 5,},

	.SS         = {.port = &PORTD, .pin = 0,},

	.MOSI       = {.port = &PORTC, .pin = 6,},

	.MISO       = {.port = &PORTC, .pin = 7,},

	.CPOL       = ACTIVE_HIGH,

	.CPHA       = FIRST_EDGE_MIDDLE,

	.SPIMODE    = EIGHTBIT,
};


/* FYI: This is the A4 wake-up pin */
/* POR state: NMI, pullup, interrupt enabled
 */
void NMIVector(void)
{
	led_action(TOGGLE, led6);
}

void isr_porta(void)
{
	led_action(TOGGLE, led7);
};

void isr_portcd(void)
{
	led_action(TOGGLE, led8);
};

/*  When something goes wrong
 */
static void error_spin_led(struct LED led)
{
	uint32_t w = 0;
	while(1)  // something went wrong with SPI
	{
		++w;
		if(w > 400000)
		{
			led_action(TOGGLE, led);
			w = 0;
		}
	}
}

static void initialize_uart0_poll(void)
{
	/* UART0 configuration */
	struct uart_config myUART =
	{
		/* transmit = PTA2 */
		.TX = {.port = &PORTA, .pin = 2,},
		/* receive = PTA1 */
		.RX = {.port = &PORTA, .pin = 1,},
		.baud = 115200,
	};
	uart_init_poll(&UART0, &myUART);
}

static void initialize_uart0(void)
{
	/* UART0 configuration */
	struct uart_config myUART =
	{
		/* transmit = PTA2 */
		.TX = {.port = &PORTA, .pin = 2,},
		/* receive = PTA1 */
		.RX = {.port = &PORTA, .pin = 1,},
		.baud = 115200,
	};
	uart0_init_intr(&myUART);
}

void main_loop(void)
{
	led_action(ON, led5);
	led_action(ON, led6);
	led_action(OFF, led7);
	led_action(ON, led8);

	__enable_irq();
	// NVIC_EnableIRQ(PORTA_IRQn);

	/* Not yet Thu 21 July 2016 17:24:45 (PDT) because issues  with PTE2*/
	// NVIC_EnableIRQ(SPI0_IRQn);

	volatile size_t len ;
	char teststr[24] = "\r\nDevelopment...\r\n";
	len  = strlen(teststr);
	uint32_t i = 0;
	uart_write_poll(&UART0, len, (uint8_t *)teststr);

	char n;
	char ch[20];
	while(1)
	{
		++i;
		if(i > 5000000)
		{
#ifdef DEBUG_UART
			if(uart0_intr_flag_g)
			{
				uart0_intr_flag_g = false;
			}
#endif
			led_action(TOGGLE, led5);
			NVIC_SetPendingIRQ(PORTA_IRQn);
			if(!uart0_writestr_intr("NUM CHARS: "))
			{
				uart_write_poll(&UART0, len,(uint8_t *) " ouch\n");
			}

			n= num_uart0_rx_chars_avail();
			util_itoa(n, ch, 10);
			if(!uart0_writestr_intr( ch))
			{
				uart_write_poll(&UART0, len,(uint8_t *) " OUCH\n");
			}
			if(!uart0_writestr_intr( "\r\n"))
			{
				uart_write_poll(&UART0, len,(uint8_t *) " OUCH\n");
			}
			printf("\r\nBuilt with version(Git hash):\t%s\r\n", LGR_GITVERSION);
			printf("Char 'c':\t%c\r\n", 'c');
			printf("Decimal 10:\t%d\r\n", 10);
			printf("Hex 10:\t\t0x%x\r\n", 10);
			printf("Bin 10:\t\t0b%b\r\n", 10);
			printf("\r\nHello\tTab\nnewline\ttab...Yay!\r\n");
			i = 0;
		}
	}
}

int main(void)
{
	after_POR_pause();

	enable_all_port_clocks();

	initialize_gpio();

	initialize_spi0(&spi0_config);

	uint8_t vers = 0xff;

	if(!xcvr_read_8bit_reg(xcvr_addrs.RegVersion, &vers))
	{
		error_spin_led(led5);
	}

	if(vers != 0x23)
	{
		error_spin_led(led7);
	}

	if(!xcvr_set_outclk_div(XCVR_CLK_DIV16))
	{
		error_spin_led(led6);
	}

	enable_pll_48();

	/* UART */
	initialize_uart0();

	lgr_version(LGR_GITVERSION);

	main_loop();

	return(-1);
}

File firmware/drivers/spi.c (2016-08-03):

/*!
* \file    spi.c
* \brief   SPI API
*
* \defgroup spi
* \brief    Generalized SPI driver for the Freescale MKW01.
* @{
*/

/*
 *     Generalized SPI driver for the Freescale MKW01.
 *
 *     Original programmed by William Harrington, Theo Hill
 */

#include <stdbool.h>

#include "v1_2.h"

#include "lgr_vector.h"
#include "core_cm0plus.h"
#include "cmsis_gcc.h"
#include "clocks.h"
#include "spi.h"

bool spi0_initialized = false;

static const struct pin_assign PCS0 [] =
{
	{.module = &SPI0, .pin = {&PORTE, 16}, .alt = 2},
	{.module = &SPI0, .pin = {&PORTD, 0},  .alt = 2},
	{.module = &SPI1, .pin = {&PORTD, 4},  .alt = 2},
	{}
};

static const struct pin_assign SCK [] =
{
	{.module = &SPI0, .pin = {&PORTE, 17}, .alt = 2},
	{.module = &SPI0, .pin = {&PORTC, 5},  .alt = 2},
	{.module = &SPI1, .pin = {&PORTD, 5},  .alt = 2},
	{.module = &SPI1, .pin = {&PORTE, 2},  .alt = 2},
	{}
};

static const struct pin_assign MISO [] =
{
	{.module = &SPI0, .pin = {&PORTE, 18}, .alt = 5},
	{.module = &SPI0, .pin = {&PORTE, 19}, .alt = 2},
	{.module = &SPI0, .pin = {&PORTC, 7},  .alt = 2},
	{.module = &SPI0, .pin = {&PORTC, 6},  .alt = 5},
	{.module = &SPI1, .pin = {&PORTB, 17}, .alt = 2},
	{.module = &SPI1, .pin = {&PORTE, 3},  .alt = 2},
	{.module = &SPI1, .pin = {&PORTE, 1},  .alt = 5},
	{.module = &SPI1, .pin = {&PORTD, 7},  .alt = 2},
	{.module = &SPI1, .pin = {&PORTD, 6},  .alt = 5},
	{}
};

static const struct pin_assign MOSI [] =
{
	{.module = &SPI0, .pin = {&PORTE, 18}, .alt = 2},
	{.module = &SPI0, .pin = {&PORTE, 19}, .alt = 5},
	{.module = &SPI0, .pin = {&PORTC, 7},  .alt = 5},
	{.module = &SPI0, .pin = {&PORTC, 6},  .alt = 2},
	{.module = &SPI1, .pin = {&PORTB, 17}, .alt = 5},
	{.module = &SPI1, .pin = {&PORTE, 3},  .alt = 5},
	{.module = &SPI1, .pin = {&PORTE, 1},  .alt = 2},
	{.module = &SPI1, .pin = {&PORTD, 7},  .alt = 5},
	{.module = &SPI1, .pin = {&PORTD, 6},  .alt = 2},
	{}
};

#define     SPI_C1_SSOE             (0b1 << 1)
#define     SPI_C1_CPOL_LOW         (0b1 << 3)
#define     SPI_C1_CPHA_START       (0b1 << 2)
#define     SPI_C1_MASTER_EN        (0b1 << 4)
#define     SPI_C1_SPTIE            (0b1 << 5)
#define     SPI_C1_SPE              (0b1 << 6)
#define     SPI_C1_SPIE             (0b1 << 7)

#define     SPI_C2_MODFEN           (0b1 << 4)
#define     SPI_C2_SPIMODE          (0b1 << 6)

#define     SPI_S_SPTEF             (0b1 << 5)
#define     SPI_S_SPRF              (0b1 << 7)

/*
 * SPI0 is directly connected to the transceiver on this SiP
 *
 * SPI0 is clocked by BUS CLOCK, SPI1 is clocked by SYSTEM CLOCK
 */
void initialize_spi0(struct spi_config * cfg)
{
	set_pin_alt(SCK,  &SPI0, &cfg->SCK);
	set_pin_alt(MOSI, &SPI0, &cfg->MOSI);
	set_pin_alt(MISO, &SPI0, &cfg->MISO);

	/*
	 * 8.3.3 MKW0xxx SPI Transaction Timing
	 * As defined in Section 8.3.2, the SPI transaction protocol is composed of two or more bytes per frame.
	 * Although the transceiver is capable of a continuous bit transfer for the entire frame, the MCU SPI port only
	 * transfers payload in bursts of 8 bits. There are implications in the way the MCU SPI is programmed and used:
	 * • The MCU SS signal -
	 * — Cannot be programmed for SPI module master mode driven operation
	 * — Port signal PTE3 must be enabled and programmed as a GPIO output to provide the required
	 * SS signal timing
	 * • The transaction bytes are sent as a bursts as allowed by the MCU 8-bit SPI module.
	 * Because the MCU is embedded in the SiP and the transceiver only supports the one clock format, the MCU
	 */

	/* We need to control the slave select manually with PTD0 set as GPIO
	 * to perform SPI operations longer than one byte
	 */
	// Can't do this for SPI0 on this chip: set_pin_alt(PCS0, SPI, &cfg->SS);

	PORTD.PCR[0] |= ALT1;       // Enable PTD0 as a GPIO
	PORTD.PCR[0] |= 0b11;       // Enable pullup
	GPIOD.PDDR   |= PTD0;       // Set PTD0 payload direction to output
	GPIOD.PTOR   =  PTD0;       // Set the output signal to high

	/* \todo Thu 21 July 2016 17:16:11 (PDT) finish this and rethink it after PTE2 reconnection
	PORTE.PCR[2] |= ALT1;
	PORTE.PCR[3] |= ALT1;
	GPIOE.PDDR   &= ~(PTE2 | PTE3); // set to input
	*/

	enable_spi0_clock();

	{
		// baud rate
		/*
		 * Section 8.2 transceiver reference manual
		 *    Programmable SPI clock rate; maximum transfer rate is 10 MHz as determined by the transceiver
		 */
		// SPI0.BR = 0x22; // 12 Mhz Bus Clock -> 500khz SPI0
		SPI0.BR = 0x0;     // 12 Mhz Bus Clock -> 6Mhz SPI0
	}

	{
		// C1
		uint8_t spi_c1  = 0x0;

		spi_c1  |= SPI_C1_SSOE | SPI_C1_MASTER_EN | SPI_C1_SPTIE | SPI_C1_SPE | SPI_C1_SPIE ;
		if(cfg->CPOL == ACTIVE_LOW)
		{
			spi_c1 |= SPI_C1_CPOL_LOW;
		}
		if(cfg->CPHA == FIRST_EDGE_START)
		{
			spi_c1 |= SPI_C1_CPHA_START;
		}
		SPI0.C1 = spi_c1;
	}

	{
		// C2
		uint8_t spi_c2  = 0x0;

		spi_c2      |=  SPI_C2_MODFEN;
		if(cfg->SPIMODE == SIXTEENBIT)
		{
			spi_c2 |= SPI_C2_SPIMODE;
		}
		else
		{
			spi_c2 &= ~(SPI_C2_SPIMODE);
		}

		SPI0.C2     =   spi_c2;
	}
	spi0_initialized = true;
}

static inline void _spi_set_8bit(void)
{
	SPI0.C2 &= ~(SPI_C2_SPIMODE);
}

static inline void _spi_set_16bit(void)
{
	SPI0.C2 |= SPI_C2_SPIMODE;
}

static inline bool _spi0_rx_buff_full(void)
{
	return((SPI0.S & SPI_S_SPRF) != 0);
}

static inline bool _spi0_tx_buff_full(void)
{
	return((SPI0.S & SPI_S_SPTEF) == 0);
}

bool _spi0_8_poll(uint8_t addr, uint8_t payload, uint8_t * buffer)
{
	if(buffer == NULL)
	{
		return false;
	}

	/* Will clear FIFO and Reset the SPI0.S register. any current transaction will be aborted */
	_spi_set_8bit();

	GPIOD.PCOR |= PTD0;   // _NSS low

	while(_spi0_tx_buff_full());

	SPI0.DL = addr;

	while(_spi0_tx_buff_full());
	while(!(_spi0_rx_buff_full()));

	*buffer = SPI0.DL;

	while(_spi0_tx_buff_full());

	SPI0.DL = payload;

	while(_spi0_tx_buff_full());

	while(!(_spi0_rx_buff_full()));

	*buffer = SPI0.DL;

	GPIOD.PSOR |= PTD0;   // _NSS high

	return true;
}

bool spi0_read_8_poll(uint8_t addr, uint8_t * buffer)
{
	uint8_t payload = 0x0;
	return _spi0_8_poll(addr, payload, buffer);
}

bool spi0_write_8_poll(uint8_t addr, uint8_t payload)
{
	uint8_t buffer = 0xff;
	/* Mask bit 7 of write address */
	addr = addr | 0x80;
	return _spi0_8_poll(addr, payload, &buffer);
}


/*! @} */

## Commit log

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2015-11-30 Firmware tools first pass
    This should provide everything needed to get started programming the
    kw01zxxx board. Main is in c3.c, you'll want to start poking about in
    there.
    Currently there's still an issue with watchdogs sometimes interrupting
    debugging, if writing the firmware fails, try it again and it should go
    through.
    [olimex_swd_kinetis.cfg]
2015-11-30 Added new make targets for creating .s files
    Original make file didn't work on my system.
    Xcode not using proper assembler.
    This is a workaround for that.
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2015-12-09 Clock configuration finished
    The MCU now boots up with the internal oscillator like it should then sets up the port and spi clocks (so that we can read/write those registers) then a small initialization procedure on the SPI0 module requests the full 32MHz signal from the transceiver. When the transceiver supplies that, we shut off all the clocks to all the modules and then dial up the PLL to create a 48 MHz clock signal. After that, we turn the clocks back on for the modules we use in this code (which aren't much some are even completey unnecessary) then blink some LEDs because thats what we do in computer engineering is blink LEDs. Now lets get this thing space ready so we can blink LEDs ou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
2015-12-16 First revision of SPI driver
    Generalized SPI driver to SPI transaction frame. Need to continue generalizing. Also made some small corrections to transceiver mapping header file.
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2015-12-17 More memory map stuff done
    Caught some padding mistakes. Introduced MTB, ADC, DMA, and maybe some others. Still not quite done.
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2015-12-26 fixed arguments for function prototypes
2016-01-08 Disable watchdog in openocd
    Note this will requre Openocd 0.10.0 which isn't released yet. Compile
    it from source
    [olimex_swd_kinetis.cfg]
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2016-01-12 Added halting gdb-attach event
    This should make it easier to connect gdb to openocd. Now there is no
    need to telnet in and stop the target before attaching gdb.
    [olimex_swd_kinetis.cfg]
2016-01-13 Change spi driver to pass peripheral by pointer
    Passing by value means the struct gets copied to an arbitrary location
    in memory - any modifications won't change the actual memory mapped
    peripheral.
2016-01-13 Moved alt pin configuration inside the spi driver
    The spi driver knows which pins should be given which alt selection, so
    lets have it do so automatically insted of allowing the user to get it
    wrong.
    This current implementation is mostly there, but isn't perfect. Still
    left to do:
    - Have it make selections given which spi peripheral is passed in. This
    information should be encoded in the struct pin_assign arrays;
    - The driver should yell loudly when an invalid pin is provided. First
    step should probably be a runtime assert.
    - Long term the configuration should be done statically at compile time.
    Then we can pull in static_assert()s so that it will not compile when
    an invalid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
2016-01-13 Added spi driver information to spi pinout config
    spi_init will now be able to check the correct pin, and set its alt
    function correctly or cause an abort if the pin is wrong.
    [spi.c]
2016-01-13 Fixed compile errors in spi driver
    Oh how I wish C would do what I meant instead of what I wrote. Having to
    add & pretty much everywhere is kind of lame and remembering to write
    volatile struct * peripheral will probably get tiring soon. I may
    re-think the declaration scheme I had going in the near future, but not
    until I try the full static config first.
    [spi.c]
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2016-02-13 Finished initial UART driver
    Finished initial UART driver. It compiles. Fixed some stuff in the SPI driver as well. Everything compiled.
    [spi.c, uart.c]
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2016-02-14 POR reset bug
    MCU wasn't behaving as expected after Power-on reset. This was due to the fact that the transceiver is unavailable for 10ms after a POR. I added a delay loop in the beginning of main to resolve the issue.
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2016-02-20 Fixed transceiver compile bug
    Had to add include guards. Also extern for global transceiver struct. Cleaned up header organization. Had to include spi.h in c3.c. Also modified configure transceiver function to now allow for controlling power output.
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2016-02-27 added provision in makefile for my poorly organized toolchain, fixed c3 bug for packet.c
    [port.c, spi.c]
2016-02-27 trying to track down spi bug, compiles right now but not behaving as it should be
2016-02-27 fixed bug in spi driver, commented out stuff in c3 in an attempt to get back to a working state
    [spi.c]
2016-02-27 Split schematic, added SPI cache symbol/fp, updated LL design
    [sputnik_prototype_RadioCom.brd, sputnik_prototype_RadioCom.sch]
2016-02-28 Added GPIOs and other updates on SysCon sch. Updated SPI cache footprint
    [sputnik_prototype_RadioCom.brd, sputnik_prototype_RadioCom.sch]
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2016-03-03 added attributes to several parts, started organizing the board to prep for layout
    [sputnik_prototype_RadioCom.brd, sputnik_prototype_RadioCom.sch]
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2016-03-04 threw configure_transceiver back into c3, seems to be working, fixed transceiver driver bugs
2016-03-05 Fixed OIs, fixed SysCon LDO, replaced SPI cache
    [sputnik_prototype_RadioCom.brd, sputnik_prototype_RadioCom.sch]
2016-03-05 Fixed to do list
    [sputnik_prototype_RadioCom.sch]
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2016-03-17 Added 22 pinout, no footprint yet, also did RF_GND
    [sputnik_prototype_RadioCom.brd, sputnik_prototype_RadioCom.sch]
2016-03-18 Updated Enable lines, switch is gonna be moved to SysCon board
    [sputnik_prototype_RadioCom.brd, sputnik_prototype_RadioCom.sch]
2016-03-18 fixed symbols
    [sputnik_prototype_RadioCom.brd, sputnik_prototype_RadioCom.sch]
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2016-03-19 Lots of OCD cleanup on schematic, bringing up to PSAS standards. Fixed lack of bypass cap on SPI flash, changed SPI flash KW0x pins to SPI1 which weren't before (?), removed DIO1 and DIO0 from GPIO b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
    [sputnik_prototype_RadioCom.brd, sputnik_prototype_RadioCom.sch]
2016-03-21 Added 44pin symbol and pull-up lines on SPI Cache
    [sputnik_prototype_RadioCom.brd, sputnik_prototype_RadioCom.sch]
2016-03-21 Fixed 22x2pinout, added PWR LEDs, fixed some NC issues
    [sputnik_prototype_RadioCom.brd, sputnik_prototype_RadioCom.sch]
2016-03-21 Added more LEDs, filled in LNA values except one inductor which I still need to figure out
    [sputnik_prototype_RadioCom.brd, sputnik_prototype_RadioCom.sch]
2016-03-22 Added RESET (RF) line to PTE2 GPIO. Waiting on LNA component values from MAACOM.
    [sputnik_prototype_RadioCom.brd, sputnik_prototype_RadioCom.sch]
2016-03-22 OCD fixes on SPI flash. Made single nets on GPIO that aren't connected. Made new connectors for OreSat connector and RF connector and added them. Updates to a library part for the outline. Made it 4 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
    [sputnik_prototype_RadioCom.brd, sputnik_prototype_RadioCom.sch]
2016-03-22 Uhh.... I did stuff? Fixed something? I can't remember. Found another NC on the KW0x.
    [sputnik_prototype_RadioCom.brd, sputnik_prototype_RadioCom.sch]
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2016-03-24 Board update. Curious now about the AC blocking network on the RFInput side. I'm not sure how you can use the RF switch without breaking the ground plane?
    [sputnik_prototype_RadioCom.brd]
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2016-03-25 Organized LED locations, test points, need to talk to Glenn about crossing RF paths because the switch inputs are reverse of the RFIO and PA_BOOST outputs.
    [sputnik_prototype_RadioCom.brd]
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2016-03-26 Poor Jake. It's like there's some crazy guy screwing with him every time he commits... oh, wait. Huh. Anyway. Updated board outline with keepouts. Moved connectors into position and locked. Added shi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
    [sputnik_prototype_RadioCom.brd, sputnik_prototype_RadioCom.sch]
2016-03-26 Yep, that was a good idea. I added the other shield. And experimented with other layouts. Still needs a ton of work, but now it's going to be OK. OH CRAP the RXTX switch might have be wired the other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
    [sputnik_prototype_RadioCom.brd, sputnik_prototype_RadioCom.sch]
2016-03-26 Attached bypass caps, made some connections between LDO and SPI cache components
    [sputnik_prototype_RadioCom.brd]
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2016-03-30 Fixed symbol pins and locations
    [sputnik_prototype_RadioCom.brd, sputnik_prototype_RadioCom.sch]
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2016-03-30 Started working on GPIOs. Finished V_LNA and VPA lines
    [sputnik_prototype_RadioCom.brd]
2016-03-31 All that's remaining is one annoying airwire and test points
    [sputnik_prototype_RadioCom.brd]
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2016-04-01 Added some review text from Glenn for changing later
    [sputnik_prototype_RadioCom.brd, sputnik_prototype_RadioCom.sch]
2016-04-01 Added some more notes to the schematic for future changes
    [sputnik_prototype_RadioCom.sch]
2016-04-02 Started converting to RF_GND, routed a line for Jake.
    [sputnik_prototype_RadioCom.brd, sputnik_prototype_RadioCom.sch]
2016-04-02 Added datasheets for ferrite bead and inverter. Made inverter and ferrite footprints and symbols and added them to the board/schematic. Fixed RF GND issue except for the KW0x pins. Added all bypass c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
    [sputnik_prototype_RadioCom.brd, sputnik_prototype_RadioCom.sch]
2016-04-02 Moved power plane from under the RF portion of the board. Changed RF trace width to calculated 0.343mm.
    [sputnik_prototype_RadioCom.brd]
2016-04-02 Fixed some overlapping lines, added RF_GND traces to GND_PA1 & GND_PA2 on the KW0x
    [sputnik_prototype_RadioCom.brd, sputnik_prototype_RadioCom.sch]
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2016-04-02 Finished placing test points, finished all unrouted airwires, got rid of all drill clearance errors. There are DRC errors of some of the polygons and other areas I'm not sure about.
    [sputnik_prototype_RadioCom.brd, sputnik_prototype_RadioCom.sch]
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2016-04-07 Fixed polygon overlap using rank. A few other minor DRC cleanups. Time for a big design review!
    [low-gain-radio.brd, low-gain-radio.sch]
2016-04-07 Updated pinout trace lines to fix DRC
    [low-gain-radio.brd]
2016-04-07 Fixed some part sizes. I'm not gonna talk about it since Andrew will surely fire me.
    [low-gain-radio.brd, low-gain-radio.sch]
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2016-04-07 Added test point names, fixed some ugly traces
    [low-gain-radio.brd, low-gain-radio.sch]
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2016-04-08 Fixed RF_GND/GND warnings by creating new RF_GND symbol in oresat-eagle-libraries. Added bypass cap on TX/RX inverter.
    [low-gain-radio.brd, low-gain-radio.sch]
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2016-04-12 Poor, poor Jake. We just axe murdeded his board. Figured out RF and digital ground, and decided to route power through the RF ground entry point. Added TOVA test point, which is better than current o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
    [low-gain-radio.brd, low-gain-radio.sch]
2016-04-12 Changed all TOVA test points, Fixed Grid lines, Put V_PA&V_LNA lines on a different layer and changed width to 0.4mm, fixed V+ polygon shape, Fixed Tx line and LNA line spacing and grid, changed the 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
    [low-gain-radio.brd, low-gain-radio.sch]
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2016-04-13 Fixed a via that wasn't the right name
    [low-gain-radio.brd]
2016-04-14 Fixed footprint labels
    [low-gain-radio.brd, low-gain-radio.sch]
2016-04-14 Fixed one airwire, seems to be some clearance drc error for the vias under the PA? Not sure why
    [low-gain-radio.brd]
2016-04-15 Made some minor tweaks, moved bottom layer trace away from copper edge
    [low-gain-radio.brd]
2016-04-15 Fixed via stitching, added tname layer, update hotkeys (Jesus thank you Andrew)
    [low-gain-radio.brd, low-gain-radio.sch]
2016-04-15 Fixed some name positions
    [low-gain-radio.brd]
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2016-04-19 Cleanup of Jake's already excellent board. Lots of polishing layout to reduce impedance, adding vias, adding polygons, and a lot of package fixes. Also cleaned up some schematic stuff, including symb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
    [low-gain-radio.brd, low-gain-radio.sch]
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2016-04-22 Lots of OCD clean up. Package changes to have better tname/tplace and tstop layes, large cleanup on layer 15 for V+ to get as close to the ground inlet of the RF shield as possible, changes made with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
    [low-gain-radio.brd, low-gain-radio.sch]
2016-04-23 fixed baud rate calculation, did testing with UART1 tx and it works fine, something on UART0 is causing a transmission to happen immediately after enabling the transciever and it never finished..stil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
    [uart.c]
2016-04-23 Fixes and cleanups in UART driver
    - Turned some magic numbers into descriptive macros
    - Fixed UART0 clock source from internal reference to PLL
    - Reduced code duplication between uart_ and uart0_ functions
    - Fixed uart_init enabling both UART[1,2] clocks for only one driver
    - Fixed uart_read writing to UART data register instead of reading
    [uart.c]
2016-04-23 Added VPATH to makefile to avoid prefixing directories
    Now instead of drivers/spi.o we can just list spi.o and
    the makefile knows to look in the drivers directory.
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2016-04-24 fixed typo in comments for LED colors
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2016-04-25 Update Parts_Selection.md
    Fixed SPI Cache part #
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2016-04-25 Last minute changes: got Ap Note and saw lack of copper pour under KW0X, so fixed that. Also saw that the LGA pins under the chip are for the radio interface, so I disconnected those and choose a few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
    [low-gain-radio.brd, low-gain-radio.sch]
2016-04-25 Oh. Duh. The HW app note says to back off the ground plane from the microstrip. Duh. Well, usually you do that more than the trace width, so I did 0.4 mm. That's as much as I could get without it hur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
    [low-gain-radio.brd, low-gain-radio.sch]
2016-04-25 found a few things while uploading. And now I found another thing...
    [low-gain-radio.brd]
2016-04-25 Two changes: fixed a few ground traces that peeled back due to the class change on the RF lines, and flooded layer 15 with RF_GND because it was dumb we didn't do that earlier. I did go ahead and iso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
    [low-gain-radio.brd]
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2016-04-27 fixed baud rate calculation mistake
    [uart.c]
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2016-04-27 Worked on BOM formatting. Didn't get it finished tonight, I'll get it done tomorrow
    [low-gain-radio_BOM.xlsx]
2016-04-27 Finished up BOM, changed resistor attributes for zero ohm resistors since they were wrong
    [low-gain-radio.brd, low-gain-radio.sch, low-gain-radio_BOM.xlsx]
2016-04-28 Fixed some definitions, vendors and vendor PNs
    [low-gain-radio_BOM.xlsx]
2016-04-28 Update Parts_Selection.md
    Added all resistor, inductor, and capacitor parts. Still need to do descriptions for most everything. Fixed eagle reference for 40-pin header.
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2016-04-29 I added an RC oscillator calibration step in the transceiver configuration
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2016-04-30 reimplemented baud rate calc, added print out for uart bytes on rx/tx examples, added rc oscillator calibration to rx side
    [uart.c]
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2016-05-08 Replaced old with new LDOs in the BOM
    [low-gain-radio_BOM.xlsx]
2016-05-08 Started the poster. This is something we should all work on together. At the moment it doesn't look good and I've basically just inserted some place-holders. Essentially just wanted to start it off s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
2016-05-16 Made attribute changes on parts that have changed, including 1uF -> 10uF bypass caps on LDOs and the LDO attributes themselves. Andrew, need to talk to you about trying to change the part name withou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
    [low-gain-radio.brd, low-gain-radio.sch]
2016-05-16 Fixed names on LDOs
    [low-gain-radio.brd, low-gain-radio.sch]
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2016-05-21 first rev of official LGR firmware, added to makefile (make write_lgr), had to fix bug in SPI driver that was causing the LGR to crash, also added specific lgr_tx configuration function to transceive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
    [spi.c]
2016-05-21 reverted back to old SPI setup for transceiver, added back loops to substitute for memcpy and memset because they are causing kw0x to crash after init procedures, turned LNA on in LGR firmware along 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
    [spi.c]
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2016-06-06 Set FIFO fill condition to SyncAddress interrupt. RX WORKS!
    Turns out this was the only thing missing from getting stuff to receive.
    Also AFC was turned on, but we don't think it affects things, but since
    this was the only way we've tested with it successfully it's going into
    the commit. Next is to test without AFC on.
2016-06-06 Added toHex() util to uart.c
    It should be in like a utils.c or something but we don't have it yet and
    I didn't want to make it just for the one function.
    [uart.c]
2016-06-06 Added nonblocking uart_char()
    Also fixed uart_read() to really actually block
    [uart.c]
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2016-06-08 Added rxx UART command to set RSSI Threshold
    Lower case r and then a two digit ascii hex value will set the rssi to
    that value. Will print an error if not hex, or echo the command if
    successful
2016-06-08 lgr rssi set command error case fell through
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2016-06-09 Update README.md
    Fixed board image size
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2016-07-04 Attached RESET(RF) to PTE16 instead of having it attached to DIO0
    [low-gain-radio.brd, low-gain-radio.sch]
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2016-08-03 Updated firmware
    New: CMSIS submodule
    Updated drivers
    Added interrupt functionality
    printf on uart0 with interrupts
    doxygen template added
    new project organization and test project
    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
    [ClockThinking.ods, low-gain-radio.brd, low-gain-radio.sch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]
2016-08-03 PTE30 output zero and pulldown. (This is now connected to RESET RF).
    [dev.c, port.c]
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2016-08-25 Fix wrong eagle files from merge
    [psas_c3_team05.brd, psas_c3_team05.sch]
2016-08-25 Fixed wrong Eagle files for v1_2. Updated test program
    [low-gain-radio.brd, low-gain-radio.sch]
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2016-09-25 LGR SCHEMATIC AND BOARD REVISIONS
    1. Added 0 ohms on VOUT of all LDOs
    2. Created reflectometer circuit
    3. Got rid of GPIO bus to 40 pin connector
    4. Started layout for the 0ohm resistors and reflectometer but it got awfully messy and there are major changes that are going to be made to the board outline and antenna connector so I left them und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
    [low-gain-radio.brd, low-gain-radio.sch]
2016-09-26 New OreSat card v0.4 layout, meant for internal backplane positioning. Moved to MMCX conncectors. Routed RF reflectometer lines, moved stuff around to get better access to the RF-RESET, and touched u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
    [low-gain-radio.brd, low-gain-radio.sch]
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2016-09-30 added new RF switch, started layout but its unfinished, still need to hook GPIO to 40 pin connector as well
    [low-gain-radio.brd, low-gain-radio.sch]
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2016-10-02 finished with laying out the rf switch, placed and routed GPIO line for LLWU
    [low-gain-radio.brd, low-gain-radio.sch]
2016-10-05 Newest v0.4 card outline and fixed annoying via and changed text to v2
    [low-gain-radio.brd]

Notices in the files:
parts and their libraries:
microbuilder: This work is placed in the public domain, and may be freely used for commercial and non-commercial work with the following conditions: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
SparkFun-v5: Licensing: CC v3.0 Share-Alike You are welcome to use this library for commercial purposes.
